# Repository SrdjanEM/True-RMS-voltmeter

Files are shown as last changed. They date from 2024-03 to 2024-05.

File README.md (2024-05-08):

# Voltage Measurement System with LED Display

## Overview
This project presents a comprehensive solution for measuring and displaying AC voltage levels accurately. Utilizing the ICL7107 analog-to-digital converter (ADC) with a precision of 3½ digits, the system offers high-precision voltage readings in a digital format, directly interfacing with LED displays for easy readability. Designed for minimal power consumption, it is particularly suited for battery-operated devices.

## Key Features
- **High Precision Measurement:** Leverages the ICL7107 ADC for accurate voltage reading.
- **Efficient Display:** Features four 7-segment SA08-11YWA LED displays for clear output visibility.
- **Energy Efficient:** Optimized for low power consumption, ideal for battery-operated implementations.
- **Flexible Connectivity:** Utilizes FFC (Flat Flexible Cable) connectors for seamless integration and ease of maintenance.
- **Robust PCB Design:** A dual-layer PCB design with a focus on electromagnetic stability and efficiency. Features copper pours for GND on the back layer to enhance device reliability.

## Hardware Components
- **ICL7107 ADC:** The core component for analog-to-digital conversion, offering direct connectivity to LED displays.
- **AD737:** Outputs RMS value of the measured AC voltage, interfaced with the ICL7107.
- **SA08-11YWA LED Displays:** Four 7-segment displays with common anode configuration, powered by 5V.
- **FFC Connectors:** Provides a flexible and secure connection between the LED displays and the main PCB.
- **PCB Materials:** Utilizes FR4 for the dielectric layer and ENIG (Electroless Nickel Immersion Gold) for the copper surface finish for enhanced durability and solderability.

## Full schematic 
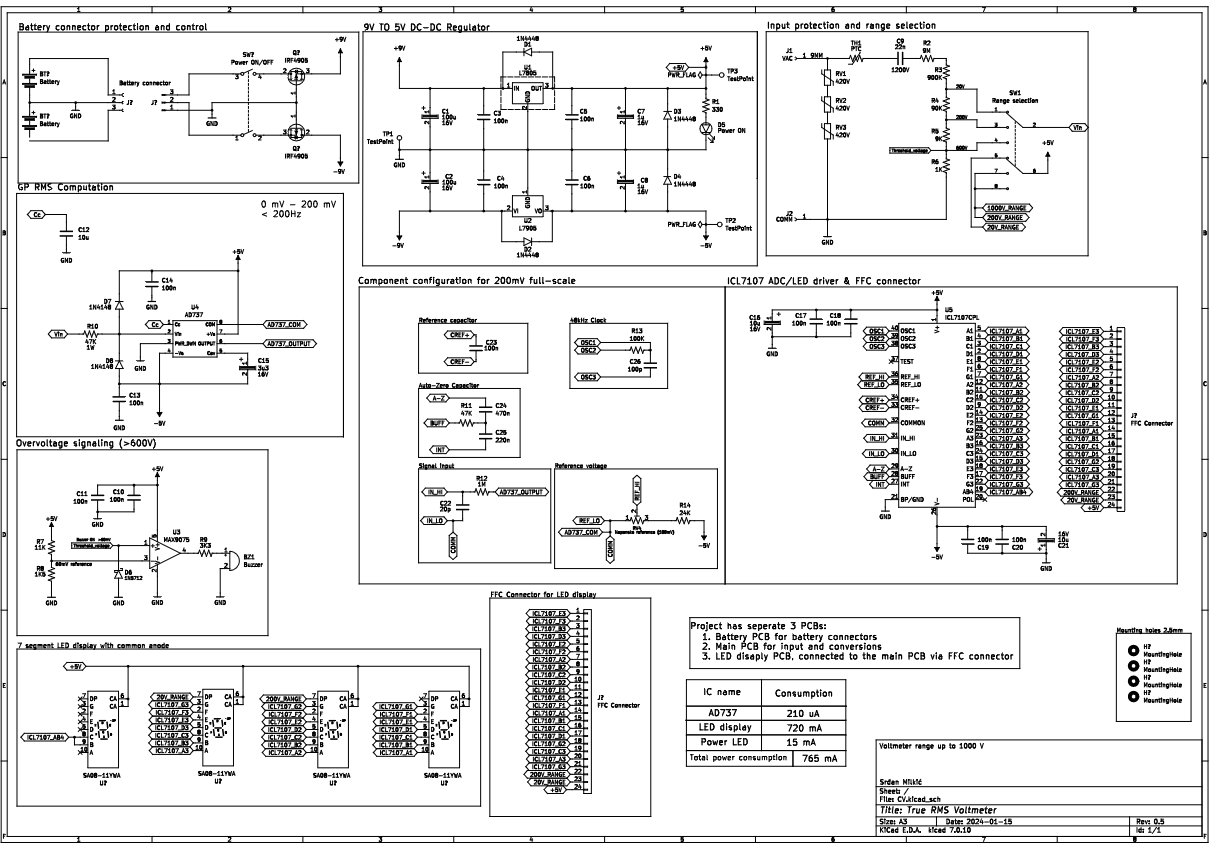
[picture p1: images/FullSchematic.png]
Schematic Better quality PDF in the repo

## PCB
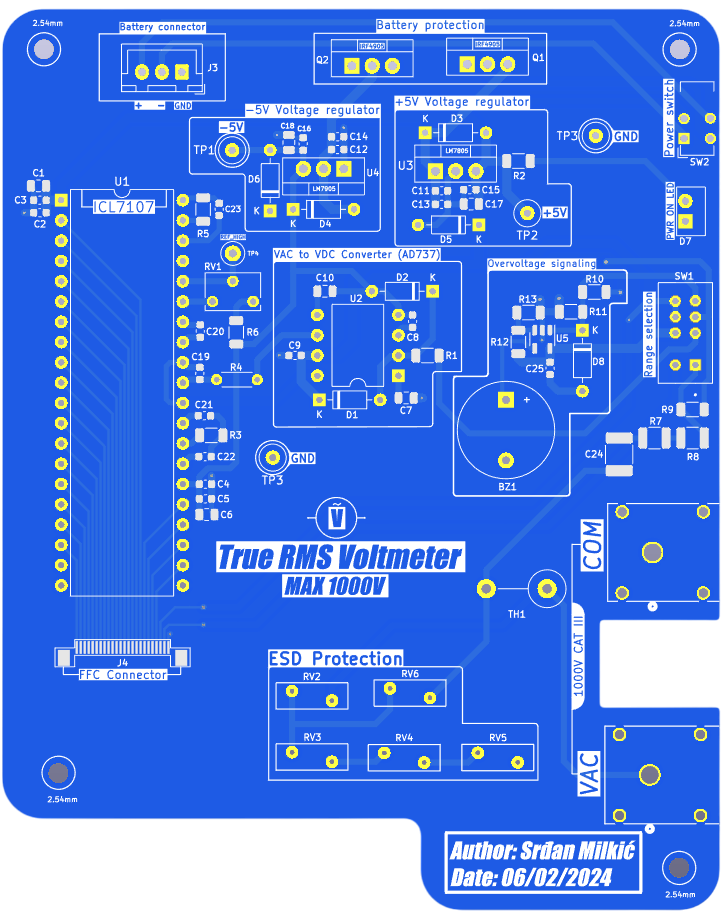
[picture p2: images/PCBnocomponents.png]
PCB PCB without components

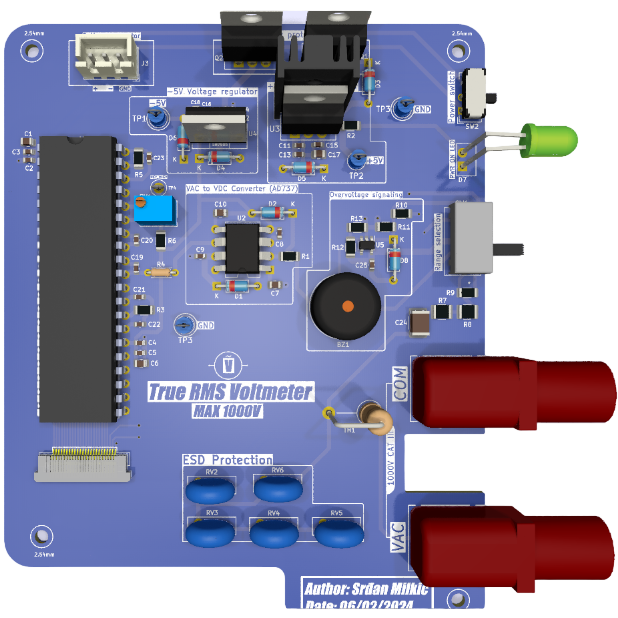
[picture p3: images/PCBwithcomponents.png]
PCB PCB with components


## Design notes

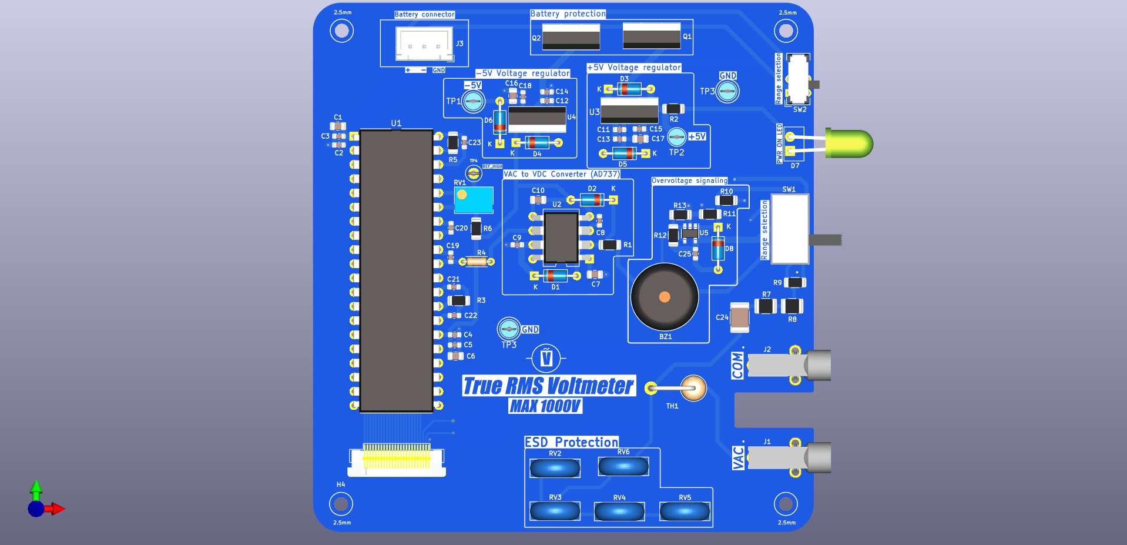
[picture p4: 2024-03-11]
True RMS Voltmeter [KiCad 7.0]/True RMS Voltmeter/Top.png

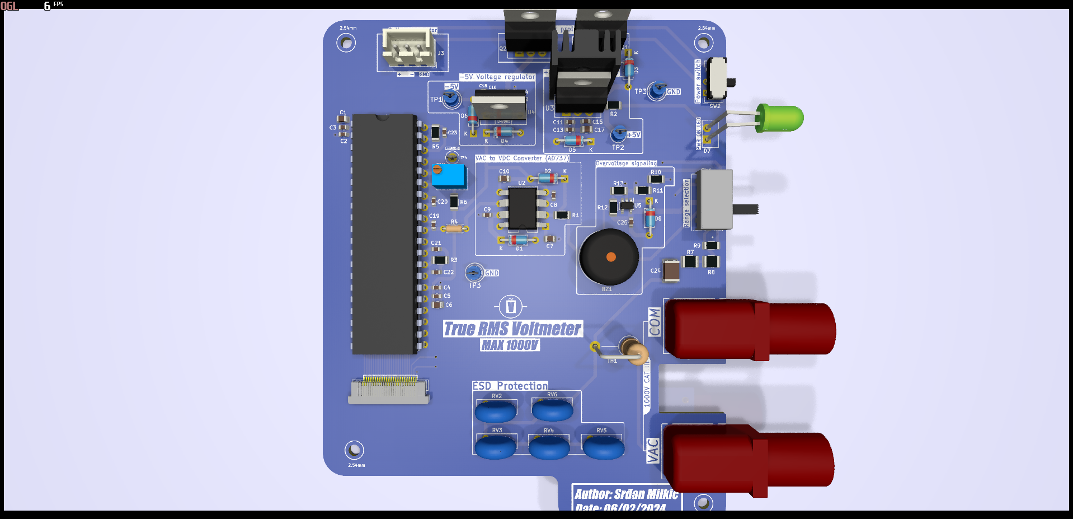
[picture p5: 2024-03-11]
True RMS Voltmeter [KiCad 7.0]/True RMS Voltmeter/TOP VIEW PCB 3D.png

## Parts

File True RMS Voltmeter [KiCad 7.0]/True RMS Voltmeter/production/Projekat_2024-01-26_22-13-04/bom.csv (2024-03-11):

Designator | Footprint | Quantity | Value | LCSC Part #
C1, C6 | 1210 | 2 | 10u
C10 | 1210 | 1 | 3u3
C11, C12 | 1210 | 2 | 100u
C13, C14, C15, C16, C2, C20, C3, C4, C5 | 1210 | 9 | 100n
C17, C18 | 1206 | 2 | 1u
C19 | 1210 | 1 | 20p
C21 | 1206 | 1 | 470n
C22 | 1206 | 1 | 220n
C23 | 1206 | 1 | 100p
C24 | C_Rect_L7.2mm_W11.0mm_P5.00mm_FKS2_FKP2_MKS2_MKP2 | 1 | 22n
C7 | 1206 | 1 | 10u
C8, C9 | 1206 | 2 | 100n
D1, D2 | D_DO-35_SOD27_P7.62mm_Horizontal | 2 | 1N4148
D3, D4, D5, D6 | D_DO-35_SOD27_P7.62mm_Horizontal | 4 | 1N4448
D7 | LED_D5.0mm_Horizontal_O6.35mm_Z15.0mm | 1 | Power ON
H1, H2, H3, H4 | MountingHole_2.5mm | 4 | MountingHole
J1 | TE_350180 | 1 | VAC
J2 | TE_350180 | 1 | COMM
J3 | JST_XH_B3B-XH-A_1x03_P2.50mm_Vertical | 1 | Conn_01x03_Male
J6 | FPC_24 | 1 | FPC Connector
Q1, Q2 | TO-220-3_Vertical | 2 | IRF4905
R1, R3 | 1206 | 2 | 47K
R10 | 1206 | 1 | 9K
R11 | 1206 | 1 | 1K
R12 | 1206 | 1 | 11K
R13 | 1206 | 1 | 1K5
R2 | 1206 | 1 | 330
R4 | 1812 | 1 | 1M
R5 | 1206 | 1 | 100K
R6 | 1206 | 1 | 24K
R9 | 1206 | 1 | 90K
RV1 | Potentiometer_Bourns_3266W_Vertical | 1 | Naponska referenca (100mV)
SW1 | SW_EG2310 | 1 | Range selection
SW2 | SW_CuK_JS202011AQN_DPDT_Angled | 1 | Power ON/OFF
TH1 | R_Axial_DIN0414_L11.9mm_D4.5mm_P7.62mm_Vertical | 1 | PTC
U1 | DIP-40_W15.24mm | 1 | ICL7107CPL
U2 | DIP-8_W10.16mm | 1 | AD737
U3 | TO-220-3_Vertical | 1 | L7805
U4 | TO-220-3_Vertical | 1 | L7905

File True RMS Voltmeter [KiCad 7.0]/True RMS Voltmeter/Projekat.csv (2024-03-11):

Source: | C:\Users\srdja\OneDrive\Radna površina\PRIUMS\Projekat\Projekat.kicad_sch
Date: | 1/13/2024 11:18:58 PM
Tool: | Eeschema (6.0.11)
Generator: | C:\Program Files\KiCad\6.0\bin\scripting\plugins/bom_csv_grouped_by_value.py
Component Count: | 52
Individual Components:
Item | Qty | Reference(s) | Value | LibPart | Footprint | Datasheet | Availability | Check_prices | Description | MANUFACTURER | MAXIMUM_PACKAGE_HEIGHT | MF | MP | PARTREV | Package | Price | Purchase-URL | SNAPEDA_PN | STANDARD | SnapEDA_Link
 |  | BZ1 | Buzzer | Device:Buzzer | Buzzer_Beeper:Buzzer_12x9.5RM7.6 | ~
 |  | C1 | 0.022uF | Device:C | Capacitor_THT:C_Rect_L26.5mm_W11.5mm_P22.50mm_MKS4 | ~
 |  | C2 | 1uF | PRIUMS_STANDARD:Cap_pol | Capacitor_SMD:C_1210_3225Metric
 |  | C3 | 100nF | Device:C | Capacitor_SMD:C_1210_3225Metric | ~
 |  | C4 | 100nF | Device:C | Capacitor_SMD:C_1210_3225Metric | ~
 |  | C5 | 3.3uF | :Cap_pol_1 | Capacitor_SMD:C_1210_3225Metric
 |  | C6 | 100uF | PRIUMS_STANDARD:Cap_pol | Capacitor_SMD:C_1210_3225Metric
 |  | C7 | 100nF | Device:C | Capacitor_SMD:C_1210_3225Metric | ~
 |  | C8 | 100nF | Device:C | Capacitor_SMD:C_1210_3225Metric | ~
 |  | C9 | 100uF | PRIUMS_STANDARD:Cap_pol | Capacitor_SMD:C_1210_3225Metric
 |  | C10 | 20pF | Device:C | Capacitor_SMD:C_1210_3225Metric | ~
 |  | C11 | 0.1uF | Device:C | Capacitor_SMD:C_1210_3225Metric | ~
 |  | C12 | 0.47uF | Device:C | Capacitor_SMD:C_1206_3216Metric | ~
 |  | C13 | 0.22uF | Device:C | Capacitor_SMD:C_1206_3216Metric | ~
 |  | C14 | 100pF | Device:C | Capacitor_SMD:C_1206_3216Metric | ~
 |  | C15 | 100uF | PRIUMS_STANDARD:Cap_pol | Capacitor_SMD:C_1206_3216Metric
 |  | C16 | 100uF | PRIUMS_STANDARD:Cap_pol | Capacitor_SMD:C_1206_3216Metric
 |  | C17 | 10pF | Device:C | Capacitor_SMD:C_1206_3216Metric | ~
 |  | D1 | 1N4148 | :1N4148_1 | Diode_THT:D_DO-35_SOD27_P7.62mm_Horizontal | https://assets.nexperia.com/documents/data-sheet/1N4148_1N4448.pdf
 |  | D2 | 1N4148 | Diode:1N4148 | Diode_THT:D_DO-35_SOD27_P7.62mm_Horizontal | https://assets.nexperia.com/documents/data-sheet/1N4148_1N4448.pdf
 |  | D3 | 1N4448 | Diode:1N4448 | Diode_THT:D_DO-35_SOD27_P7.62mm_Horizontal | https://assets.nexperia.com/documents/data-sheet/1N4148_1N4448.pdf
 |  | D4 | Green | Device:LED | LED_THT:LED_D5.0mm_Horizontal_O6.35mm_Z15.0mm | ~
 |  | D5 | 1N4002 | Diode:1N4002 | Diode_THT:D_DO-41_SOD81_P10.16mm_Horizontal | http://www.vishay.com/docs/88503/1n4001.pdf
 |  | IC1 | AD737 | PRIUMS_STANDARD:AD737 | Package_DIP:DIP-8_W10.16mm | https://www.analog.com/media/en/technical-documentation/data-sheets/ad737.pdf
 |  | J1 | COMM | Connector:Conn_01x01_Female | Connector:Banana_Jack_1Pin | ~
 |  | J2 | V | Connector:Conn_01x01_Female | Connector:Banana_Jack_1Pin | ~
 |  | J3 | Battery Connector | Connector_Generic:Conn_01x02 |  | ~
 |  | R1 | 1M | Device:R_US | Resistor_SMD:R_1812_4532Metric | ~
 |  | R2 | 11K | Device:R_US | Resistor_SMD:R_1206_3216Metric | ~
 |  | R3 | 1.5K | Device:R_US | Resistor_SMD:R_1206_3216Metric | ~
 |  | R4 | 11M | Device:R_US | Resistor_SMD:R_1210_3225Metric | ~
 |  | R5 | 47K | Device:R_US | Resistor_SMD:R_1206_3216Metric | ~
 |  | R6 | 330 | Device:R_US | Resistor_SMD:R_1206_3216Metric | ~
 |  | R7 | 47K | Device:R_US | Resistor_SMD:R_1206_3216Metric | ~
 |  | R8 | 100K | Device:R_US | Resistor_SMD:R_1206_3216Metric | ~
 |  | R9 | 100K | Device:R_US | Resistor_SMD:R_1206_3216Metric | ~
 |  | R10 | 24K | Device:R_US | Resistor_SMD:R_1206_3216Metric | ~
 |  | R11 | 10K | Device:R_US | Resistor_SMD:R_1206_3216Metric | ~
 |  | R12 | 1.1K | Device:R_US | Resistor_SMD:R_1206_3216Metric | ~
 |  | RV1 | 1K | Device:R_Potentiometer_Trim_US | Potentiometer_THT:Potentiometer_Bourns_3266W_Vertical | ~
 |  | RV2 | 430V | Device:Varistor | Varistor:RV_Disc_D12mm_W3.9mm_P7.5mm | ~
 |  | RV3 | 430V | Device:Varistor | Varistor:RV_Disc_D12mm_W3.9mm_P7.5mm | ~
 |  | RV4 | 430V | Device:Varistor | Varistor:RV_Disc_D12mm_W3.9mm_P7.5mm | ~
 |  | RV5 | 430V | Device:Varistor | Varistor:RV_Disc_D12mm_W3.9mm_P7.5mm | ~
 |  | RV6 | 430V | Device:Varistor | Varistor:RV_Disc_D12mm_W3.9mm_P7.5mm | ~
 |  | S1 | EG2310 | PRIUMS_STANDARD:EG2310 | EG2310:SW_EG2310 |  | In Stock | https://www.snapeda.com/parts/EG2310/E-Switch/view-part/?ref=eda | Slide Switch DP3T Through Hole, Right Angle | E-Switch | 4.7mm | E-Switch | EG2310 | - | None | None | https://www.snapeda.com/api/url_track_click_mouser/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 | EG2310 | Manufacturer Recommendations | https://www.snapeda.com/parts/EG2310/E-Switch/view-part/?ref=snap
 |  | TH1 | PTC | PRIUMS_STANDARD:PTC | Resistor_THT:R_Axial_DIN0414_L11.9mm_D4.5mm_P7.62mm_Vertical | https://www.vishay.com/docs/29072/ptccl.pdf
 |  | U1 | ICL7107CPL | Analog_ADC:ICL7107CPL | Package_DIP:DIP-40_W15.24mm | https://www.renesas.com/eu/en/www/doc/datasheet/icl7106-07-07s.pdf
 |  | U2 | DE113-XX-XX | Display_Character:DE113-XX-XX | Display_7Segment:DE113-XX-XX | http://www.display-elektronik.de/filter/DE113-MS-20_75.pdf
 |  | U3 | L7806 | Regulator_Linear:L7806 | Package_TO_SOT_THT:TO-220-3_Horizontal_TabDown | http://www.st.com/content/ccc/resource/technical/document/datasheet/41/4f/b3/b0/12/d4/47/88/CD00000444.pdf/files/CD00000444.pdf/jcr:content/translations/en.CD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
 |  | U4 | L7905 | Regulator_Linear:L7905 | Package_TO_SOT_THT:TO-220-3_Horizontal_TabDown | http://www.st.com/content/ccc/resource/technical/document/datasheet/c9/16/86/41/c7/2b/45/f2/CD00000450.pdf/files/CD00000450.pdf/jcr:content/translations/en.CD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
 |  | U5 | AD8561 | Comparator:AD8561 | Package_DIP:DIP-8_W7.62mm | https://www.analog.com/media/en/technical-documentation/data-sheets/ad8561.pdf
Collated Components:
Item | Qty | Reference(s) | Value | LibPart | Footprint | Datasheet | Availability | Check_prices | Description | MANUFACTURER | MAXIMUM_PACKAGE_HEIGHT | MF | MP | PARTREV | Package | Price | Purchase-URL | SNAPEDA_PN | STANDARD | SnapEDA_Link
1 | 1 | BZ1 | Buzzer | Device:Buzzer | Buzzer_Beeper:Buzzer_12x9.5RM7.6 | ~
2 | 1 | C1 | 0.022uF | Device:C | Capacitor_THT:C_Rect_L26.5mm_W11.5mm_P22.50mm_MKS4 | ~
3 | 1 | C2 | 1uF | PRIUMS_STANDARD:Cap_pol | Capacitor_SMD:C_1210_3225Metric
4 | 4 | C3, C4, C7, C8 | 100nF | Device:C | Capacitor_SMD:C_1210_3225Metric | ~
5 | 1 | C5 | 3.3uF | :Cap_pol_1 | Capacitor_SMD:C_1210_3225Metric
6 | 2 | C6, C9 | 100uF | PRIUMS_STANDARD:Cap_pol | Capacitor_SMD:C_1210_3225Metric
7 | 1 | C10 | 20pF | Device:C | Capacitor_SMD:C_1210_3225Metric | ~
8 | 1 | C11 | 0.1uF | Device:C | Capacitor_SMD:C_1210_3225Metric | ~
9 | 1 | C12 | 0.47uF | Device:C | Capacitor_SMD:C_1206_3216Metric | ~
10 | 1 | C13 | 0.22uF | Device:C | Capacitor_SMD:C_1206_3216Metric | ~
11 | 1 | C14 | 100pF | Device:C | Capacitor_SMD:C_1206_3216Metric | ~
12 | 2 | C15, C16 | 100uF | PRIUMS_STANDARD:Cap_pol | Capacitor_SMD:C_1206_3216Metric
13 | 1 | C17 | 10pF | Device:C | Capacitor_SMD:C_1206_3216Metric | ~
14 | 1 | D1 | 1N4148 | :1N4148_1 | Diode_THT:D_DO-35_SOD27_P7.62mm_Horizontal | https://assets.nexperia.com/documents/data-sheet/1N4148_1N4448.pdf
15 | 1 | D2 | 1N4148 | Diode:1N4148 | Diode_THT:D_DO-35_SOD27_P7.62mm_Horizontal | https://assets.nexperia.com/documents/data-sheet/1N4148_1N4448.pdf
16 | 1 | D3 | 1N4448 | Diode:1N4448 | Diode_THT:D_DO-35_SOD27_P7.62mm_Horizontal | https://assets.nexperia.com/documents/data-sheet/1N4148_1N4448.pdf
17 | 1 | D4 | Green | Device:LED | LED_THT:LED_D5.0mm_Horizontal_O6.35mm_Z15.0mm | ~
18 | 1 | D5 | 1N4002 | Diode:1N4002 | Diode_THT:D_DO-41_SOD81_P10.16mm_Horizontal | http://www.vishay.com/docs/88503/1n4001.pdf
19 | 1 | IC1 | AD737 | PRIUMS_STANDARD:AD737 | Package_DIP:DIP-8_W10.16mm | https://www.analog.com/media/en/technical-documentation/data-sheets/ad737.pdf
20 | 1 | J1 | COMM | Connector:Conn_01x01_Female | Connector:Banana_Jack_1Pin | ~
21 | 1 | J2 | V | Connector:Conn_01x01_Female | Connector:Banana_Jack_1Pin | ~
22 | 1 | J3 | Battery Connector | Connector_Generic:Conn_01x02 |  | ~
23 | 1 | R1 | 1M | Device:R_US | Resistor_SMD:R_1812_4532Metric | ~
24 | 1 | R2 | 11K | Device:R_US | Resistor_SMD:R_1206_3216Metric | ~
25 | 1 | R3 | 1.5K | Device:R_US | Resistor_SMD:R_1206_3216Metric | ~
26 | 1 | R4 | 11M | Device:R_US | Resistor_SMD:R_1210_3225Metric | ~
27 | 2 | R5, R7 | 47K | Device:R_US | Resistor_SMD:R_1206_3216Metric | ~
28 | 1 | R6 | 330 | Device:R_US | Resistor_SMD:R_1206_3216Metric | ~
29 | 2 | R8, R9 | 100K | Device:R_US | Resistor_SMD:R_1206_3216Metric | ~
30 | 1 | R10 | 24K | Device:R_US | Resistor_SMD:R_1206_3216Metric | ~
31 | 1 | R11 | 10K | Device:R_US | Resistor_SMD:R_1206_3216Metric | ~
32 | 1 | R12 | 1.1K | Device:R_US | Resistor_SMD:R_1206_3216Metric | ~
33 | 1 | RV1 | 1K | Device:R_Potentiometer_Trim_US | Potentiometer_THT:Potentiometer_Bourns_3266W_Vertical | ~
34 | 5 | RV2, RV3, RV4, RV5, RV6 | 430V | Device:Varistor | Varistor:RV_Disc_D12mm_W3.9mm_P7.5mm | ~
35 | 1 | S1 | EG2310 | PRIUMS_STANDARD:EG2310 | EG2310:SW_EG2310 |  | In Stock | https://www.snapeda.com/parts/EG2310/E-Switch/view-part/?ref=eda | Slide Switch DP3T Through Hole, Right Angle | E-Switch | 4.7mm | E-Switch | EG2310 | - | None | None | https://www.snapeda.com/api/url_track_click_mouser/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 | EG2310 | Manufacturer Recommendations | https://www.snapeda.com/parts/EG2310/E-Switch/view-part/?ref=snap
36 | 1 | TH1 | PTC | PRIUMS_STANDARD:PTC | Resistor_THT:R_Axial_DIN0414_L11.9mm_D4.5mm_P7.62mm_Vertical | https://www.vishay.com/docs/29072/ptccl.pdf
37 | 1 | U1 | ICL7107CPL | Analog_ADC:ICL7107CPL | Package_DIP:DIP-40_W15.24mm | https://www.renesas.com/eu/en/www/doc/datasheet/icl7106-07-07s.pdf
38 | 1 | U2 | DE113-XX-XX | Display_Character:DE113-XX-XX | Display_7Segment:DE113-XX-XX | http://www.display-elektronik.de/filter/DE113-MS-20_75.pdf
39 | 1 | U3 | L7806 | Regulator_Linear:L7806 | Package_TO_SOT_THT:TO-220-3_Horizontal_TabDown | http://www.st.com/content/ccc/resource/technical/document/datasheet/41/4f/b3/b0/12/d4/47/88/CD00000444.pdf/files/CD00000444.pdf/jcr:content/translations/en.CD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
40 | 1 | U4 | L7905 | Regulator_Linear:L7905 | Package_TO_SOT_THT:TO-220-3_Horizontal_TabDown | http://www.st.com/content/ccc/resource/technical/document/datasheet/c9/16/86/41/c7/2b/45/f2/CD00000450.pdf/files/CD00000450.pdf/jcr:content/translations/en.CD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
41 | 1 | U5 | AD8561 | Comparator:AD8561 | Package_DIP:DIP-8_W7.62mm | https://www.analog.com/media/en/technical-documentation/data-sheets/ad8561.pdf

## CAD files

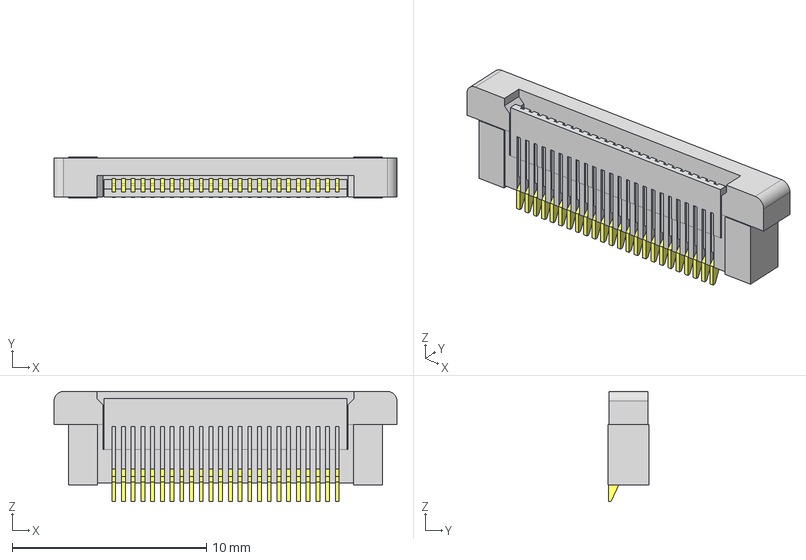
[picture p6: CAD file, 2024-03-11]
True RMS Voltmeter [KiCad 7.0]/EG2310/3D/ZF5S-24-01-T-WT.stp
17.6 x 2.10 x 5.67 mm
C-297-24-01_pins
ZF5S-24-01-WT_socket

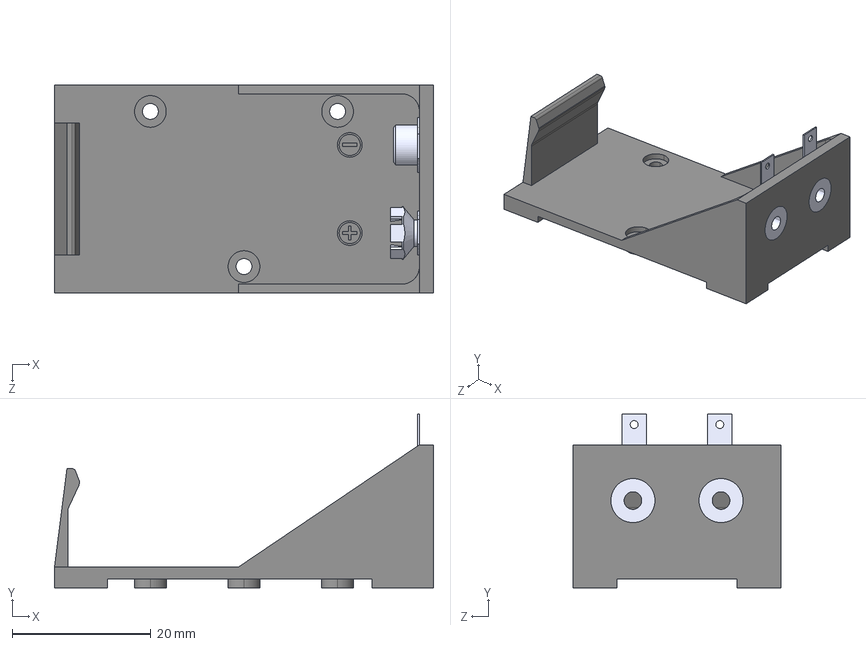
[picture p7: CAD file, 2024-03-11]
True RMS Voltmeter [KiCad 7.0]/Footprint/BH9VL--3DModel-STEP-56544/BH9VL--3DModel-STEP-56544.STEP
54.6 x 25.1 x 30.0 mm

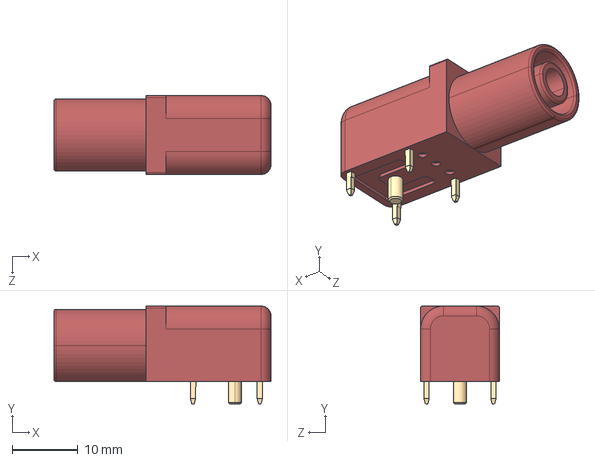
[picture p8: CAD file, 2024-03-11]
True RMS Voltmeter [KiCad 7.0]/Footprint/FCR7350R/FCR7350R--3DModel-STEP-56544.STEP
33.0 x 14.9 x 12.0 mm

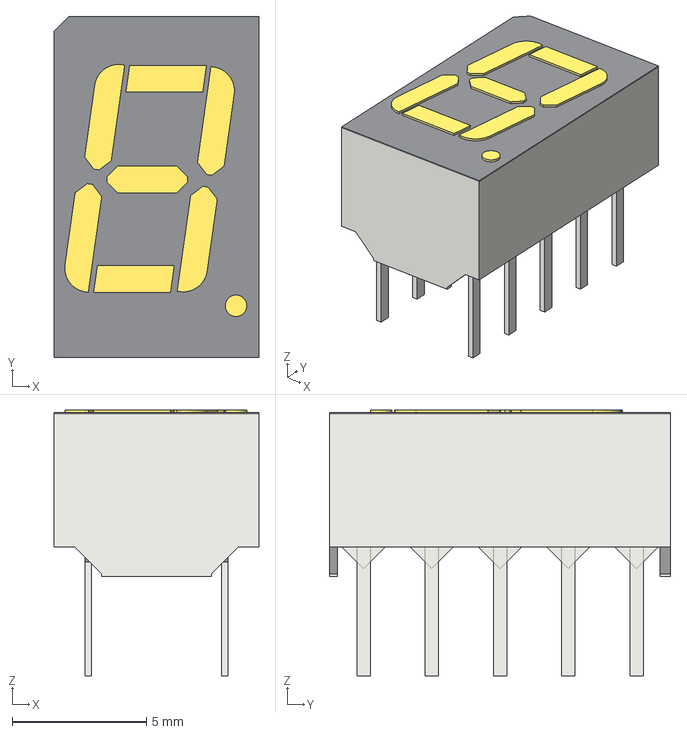
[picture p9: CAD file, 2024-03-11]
True RMS Voltmeter [KiCad 7.0]/Footprint/HDSP-7401.step
7.62 x 12.7 x 9.90 mm

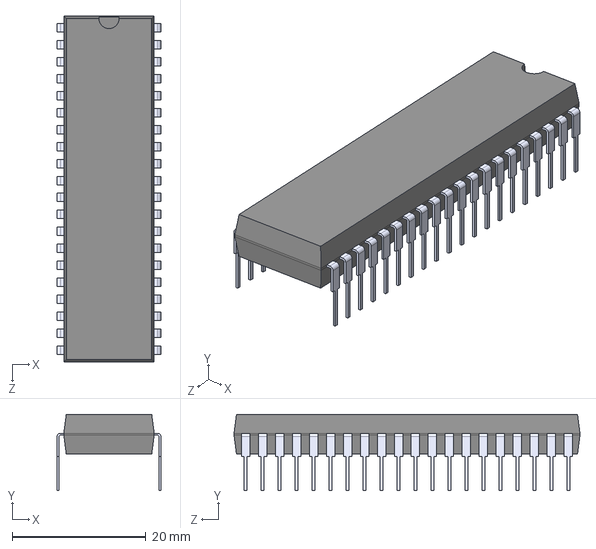
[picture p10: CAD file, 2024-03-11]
True RMS Voltmeter [KiCad 7.0]/Footprint/ICL7107/ICL7107CPL--3DModel-STEP-1.STEP
15.5 x 11.4 x 51.8 mm

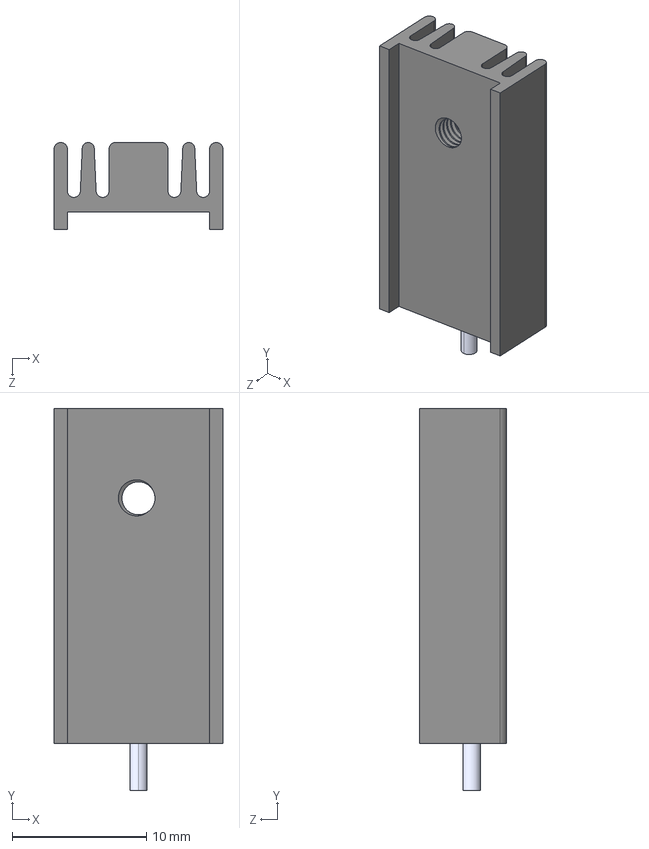
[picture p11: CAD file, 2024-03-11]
True RMS Voltmeter [KiCad 7.0]/Footprint/SK 95 25 STS TO 220/SK 95 25 STS TO 220--3DModel-STEP-269445.STEP
12.6 x 28.5 x 6.50 mm

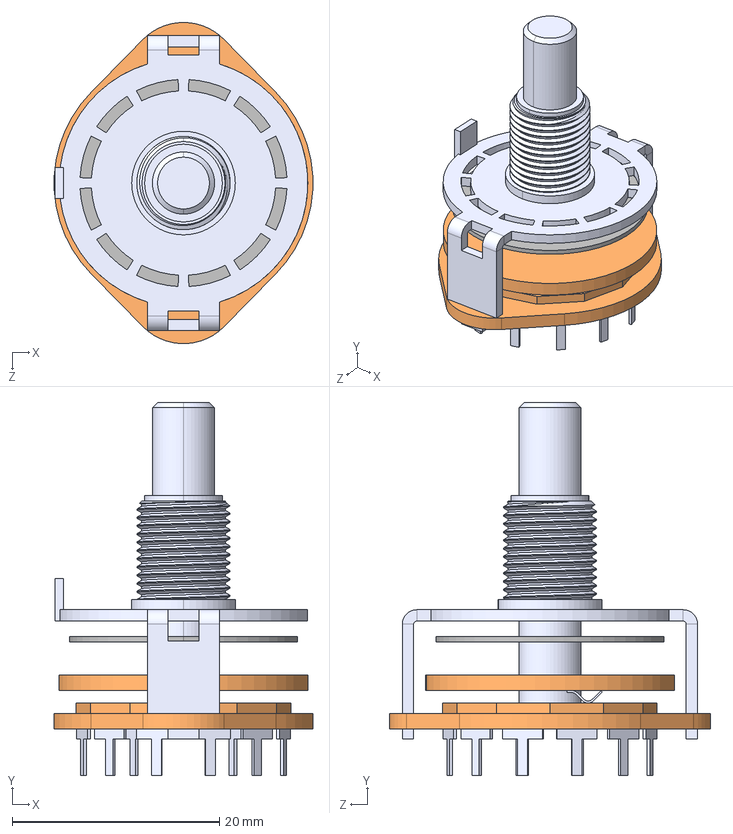
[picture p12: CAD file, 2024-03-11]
True RMS Voltmeter [KiCad 7.0]/Footprint/SR2512F-0206-19R0B-E9-N-W-159/SR2512F-0206-19R0B-E9-N-W-159--3DModel-STEP-56544.STEP
25.0 x 36.0 x 31.0 mm

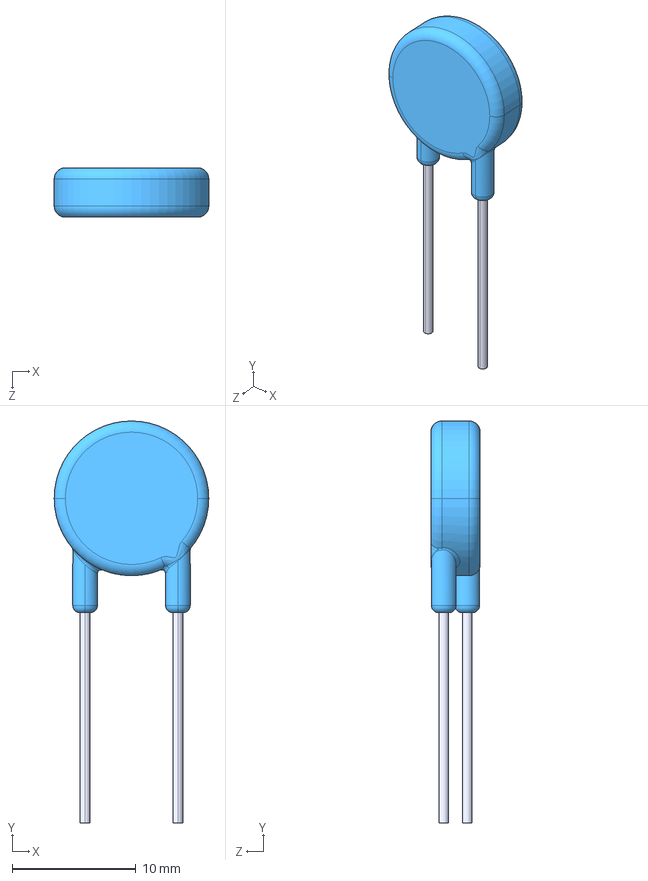
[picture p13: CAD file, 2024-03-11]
True RMS Voltmeter [KiCad 7.0]/MOV-10D561K.STEP
12.5 x 32.5 x 4.00 mm

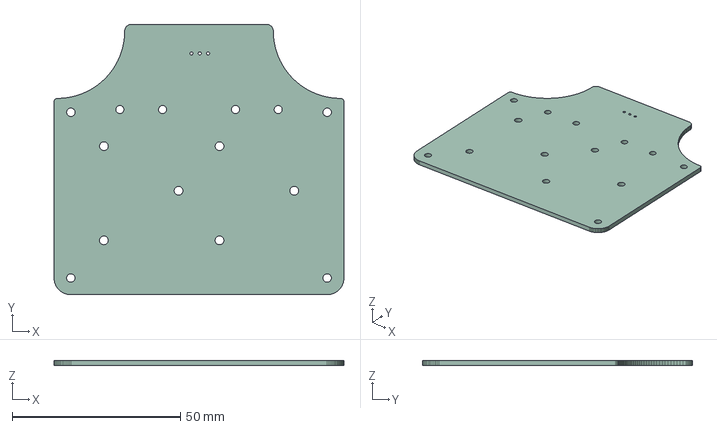
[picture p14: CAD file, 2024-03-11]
True RMS Voltmeter [KiCad 7.0]/True RMS Voltmeter/LCD Ploča/Baterija/Baterija.step
86.2 x 80.4 x 1.60 mm

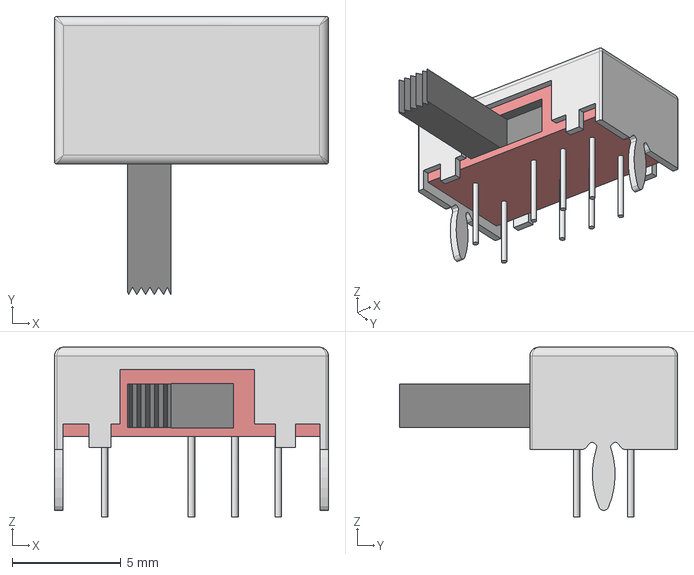
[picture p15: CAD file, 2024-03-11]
True RMS Voltmeter [KiCad 7.0]/EG2310/3D/EG2310.stp
12.6 x 12.8 x 7.80 mm

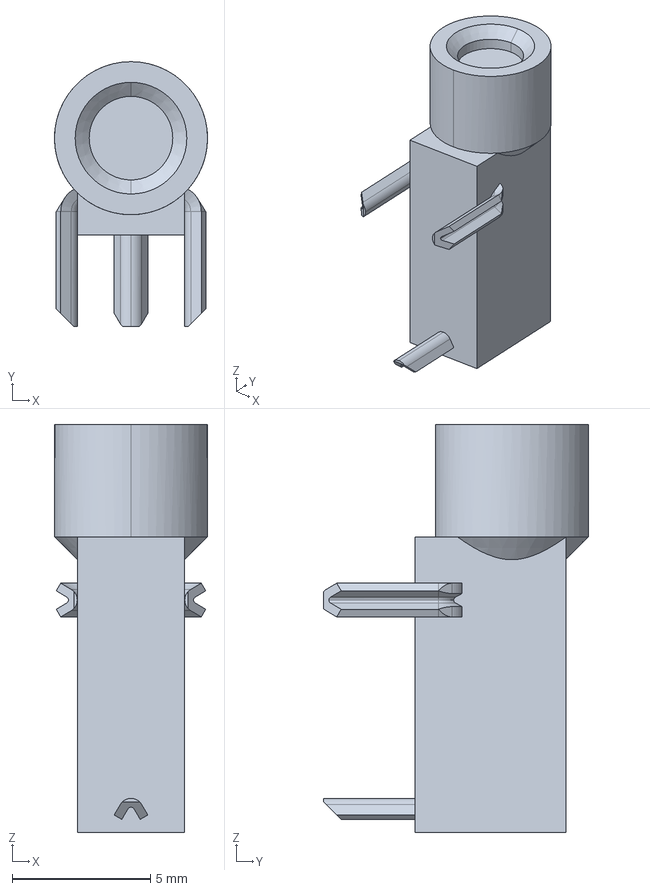
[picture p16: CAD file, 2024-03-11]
True RMS Voltmeter [KiCad 7.0]/Footprint/350180-9/350180-9.step
5.54 x 9.58 x 14.8 mm

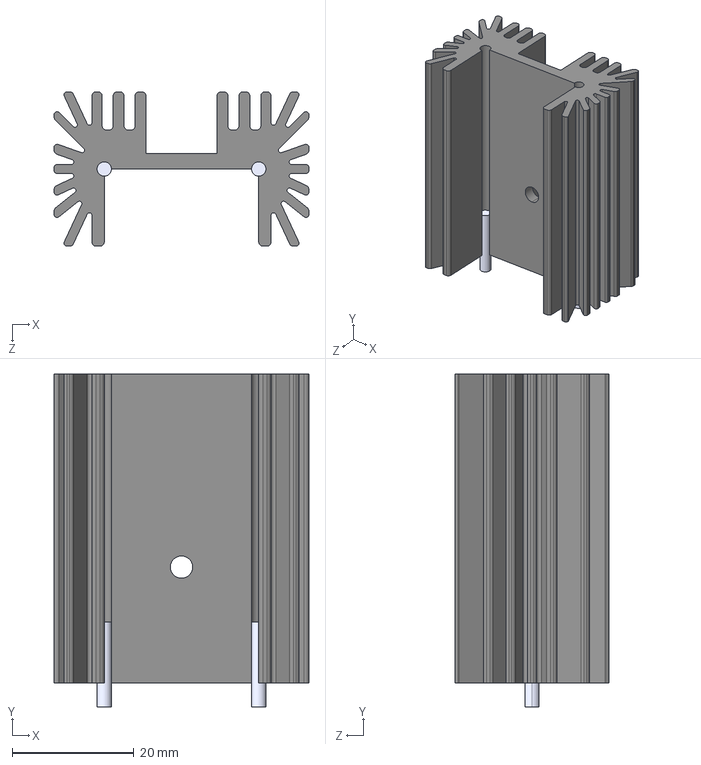
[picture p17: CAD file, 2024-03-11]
True RMS Voltmeter [KiCad 7.0]/Footprint/532702B02500G/532702B02500G.step
41.9 x 54.8 x 25.4 mm

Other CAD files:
True RMS Voltmeter [KiCad 7.0]/Footprint/ZF5S-24-01-T-WT/ZF5S-24-01-T-WT.stp

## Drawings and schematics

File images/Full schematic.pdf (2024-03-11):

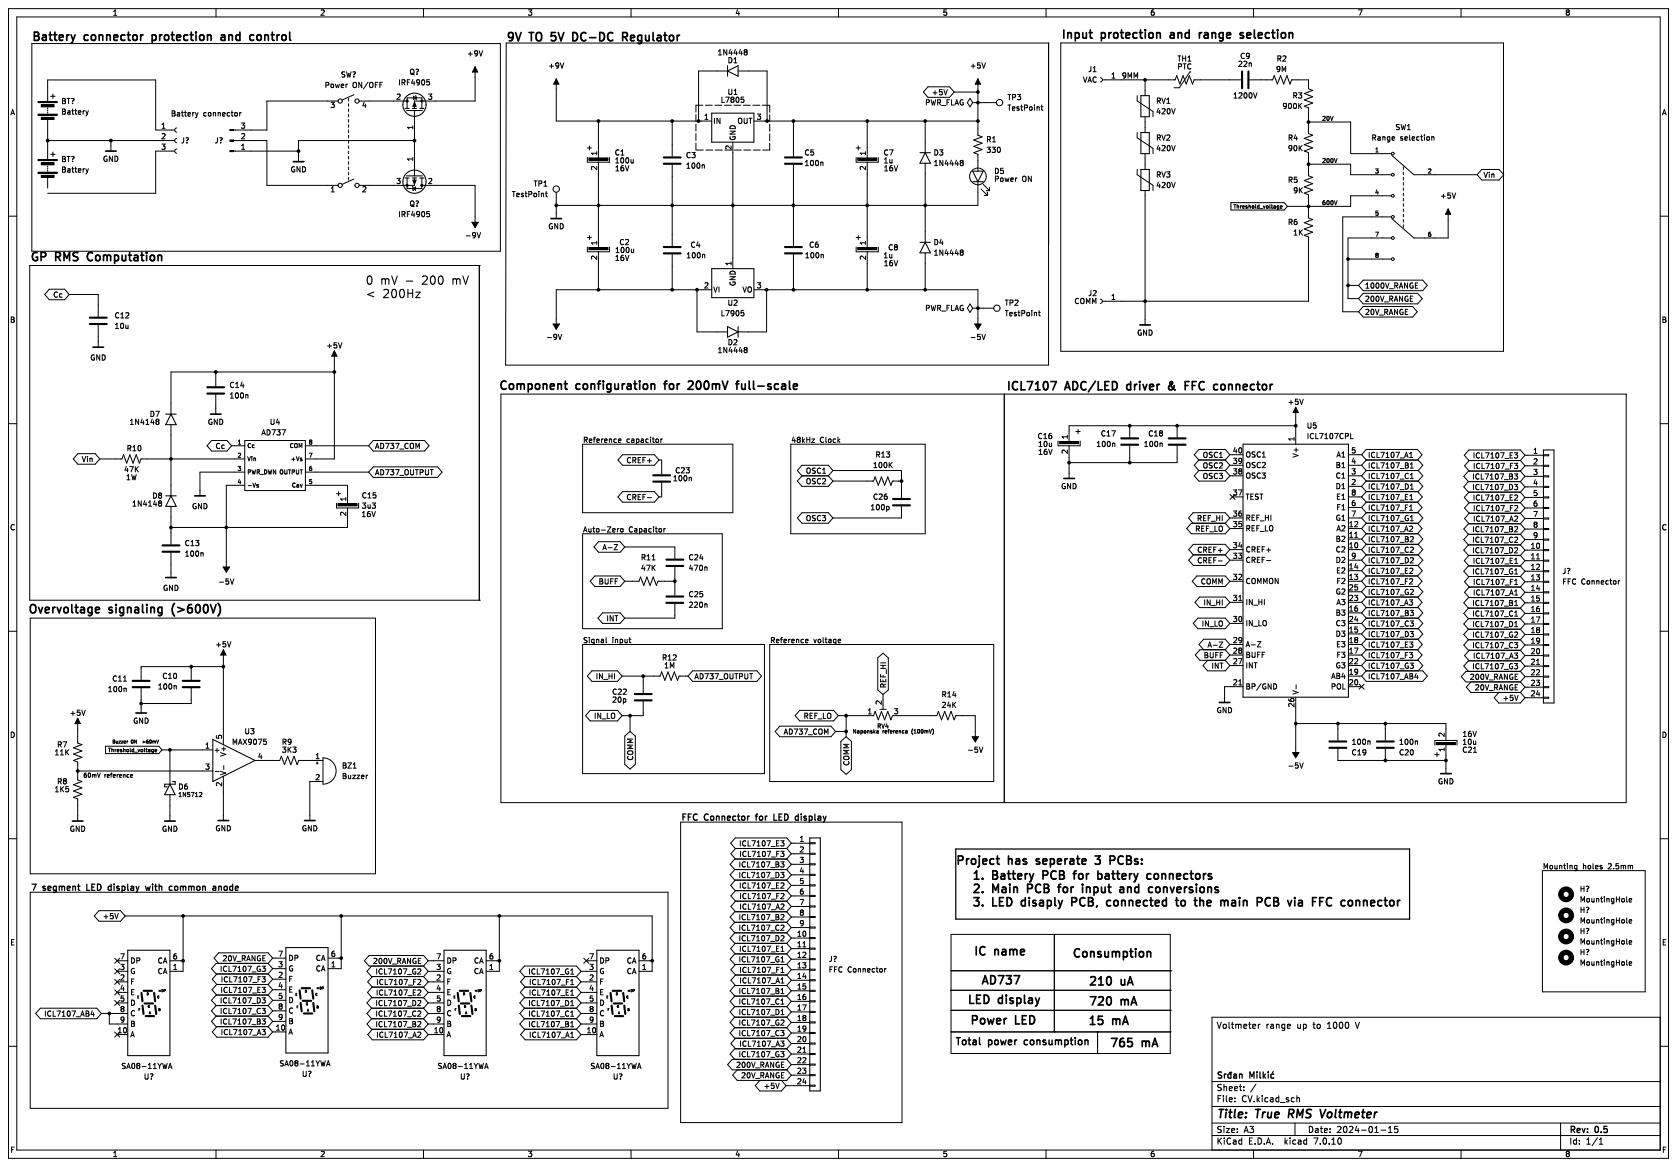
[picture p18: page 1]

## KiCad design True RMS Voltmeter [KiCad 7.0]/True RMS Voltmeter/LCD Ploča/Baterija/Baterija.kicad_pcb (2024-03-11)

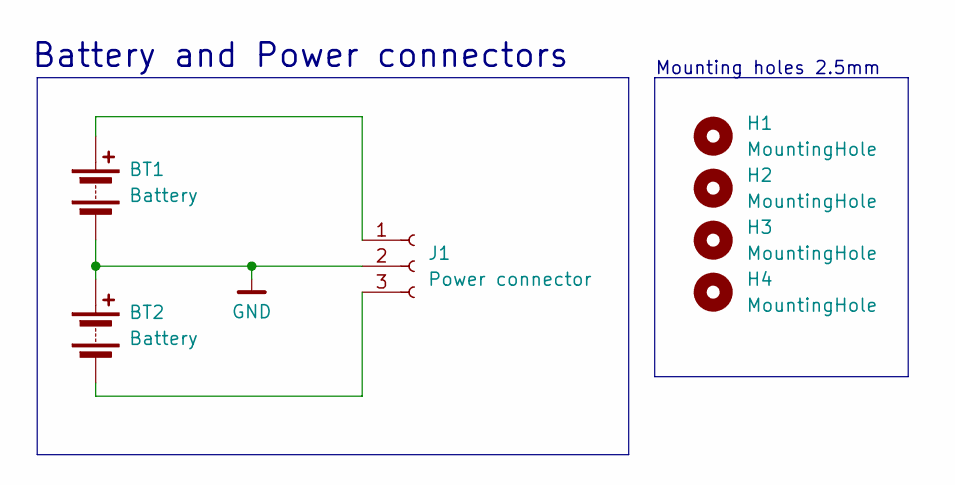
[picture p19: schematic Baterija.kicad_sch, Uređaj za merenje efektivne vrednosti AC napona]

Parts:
BT1, BT2: Battery; BatteryHolder_Eagle_12BH611-GR
H1, H2, H3, H4: MountingHole; MountingHole_2.5mm
J1: Power connector; JST_XH_B3B-XH-A_1x03_P2.50mm_Vertical

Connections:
GND: BT1.2 (-), BT2.1 (+), J1.2
unnamed: BT1.1 (+), J1.1
unnamed: BT2.2 (-), J1.3

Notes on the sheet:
Battery and Power connectors
Mounting holes 2.5mm

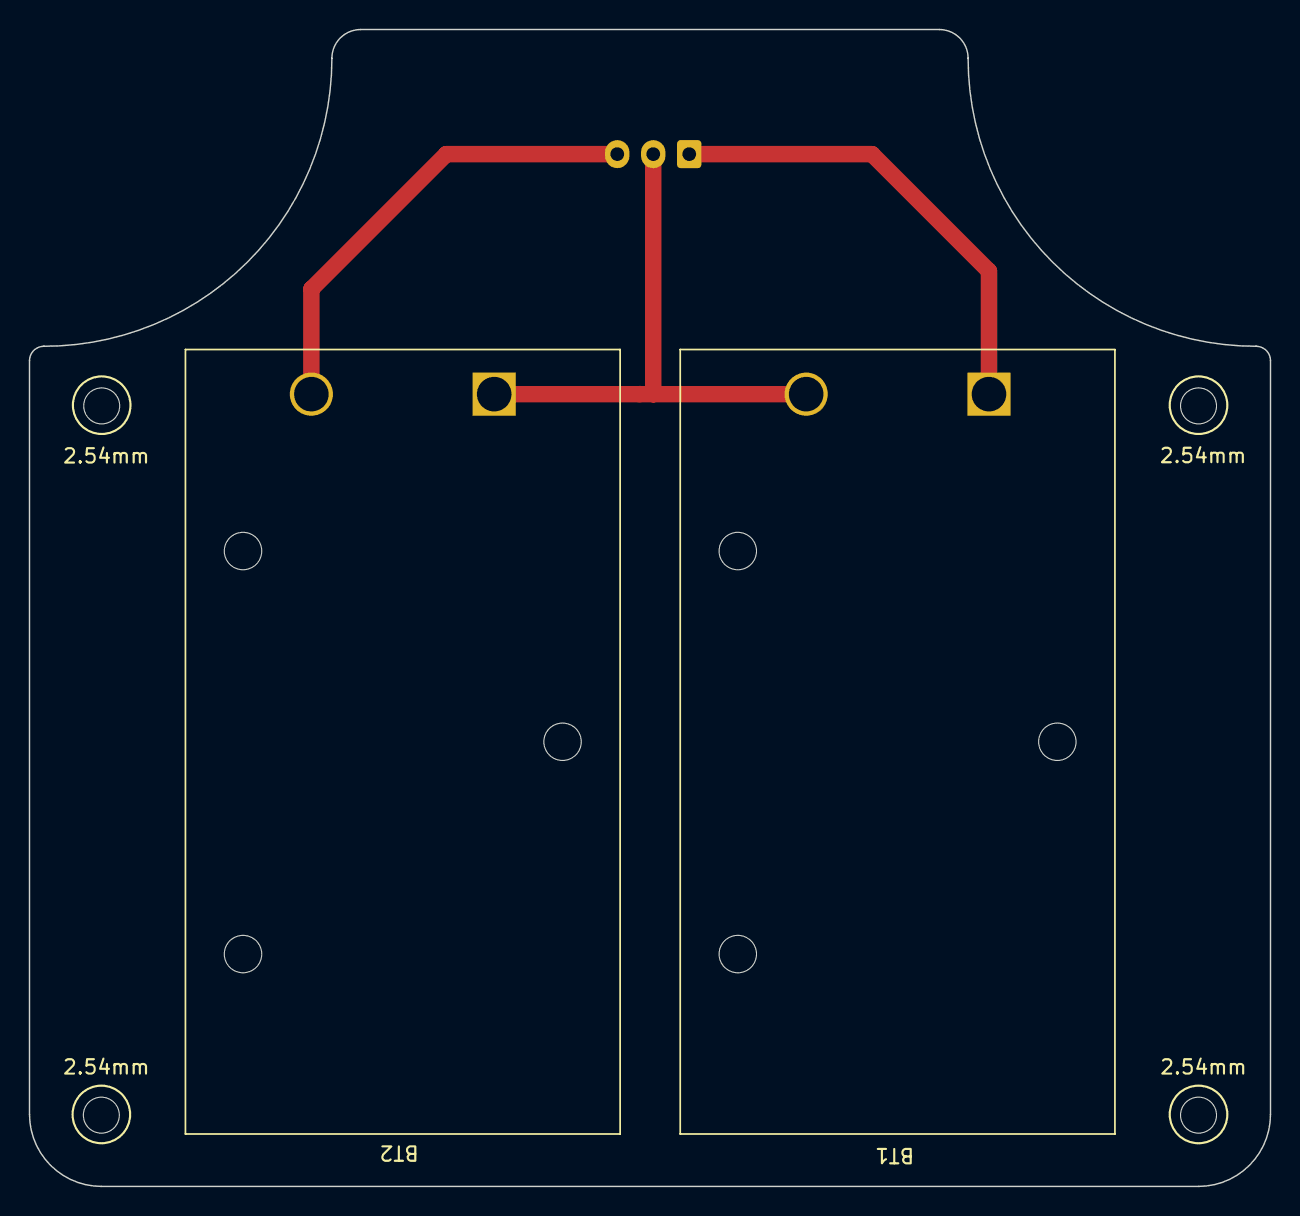
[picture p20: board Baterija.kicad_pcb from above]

Board: 2 copper layers, 86.2 x 80.4 mm, 7 parts (1 on the bottom side), 3 nets.

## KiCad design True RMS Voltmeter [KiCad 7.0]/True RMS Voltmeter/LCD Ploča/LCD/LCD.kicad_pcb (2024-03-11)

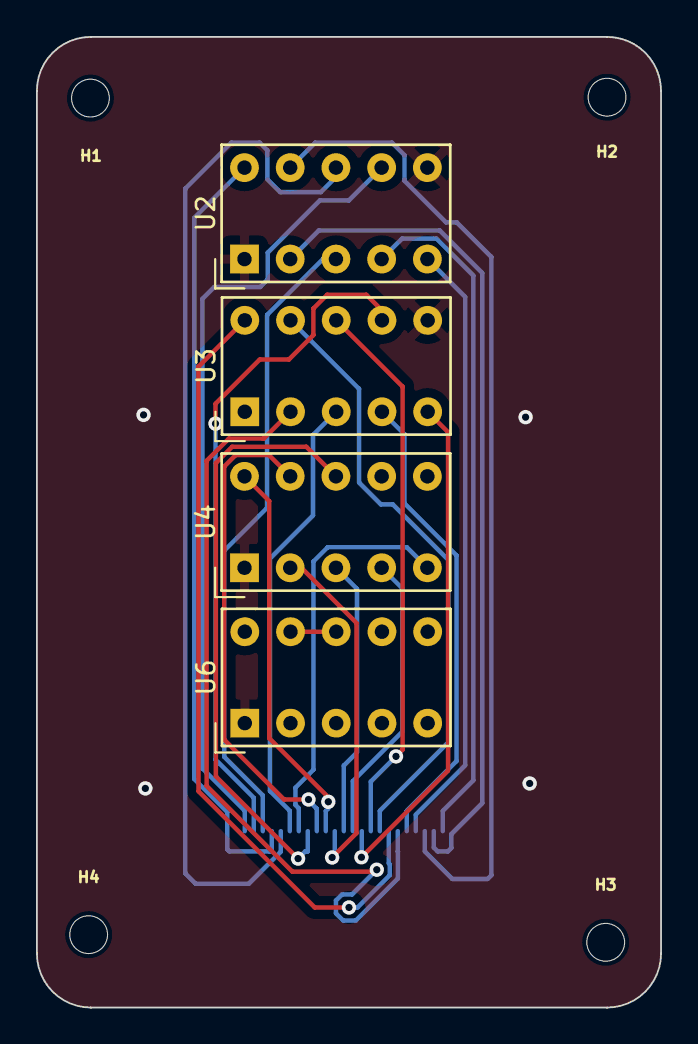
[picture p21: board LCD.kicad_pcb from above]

Board: 2 copper layers, 34.7 x 53.9 mm, 9 parts (1 on the bottom side), 25 nets.

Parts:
H1, H2, H3, H4: MountingHole; MountingHole_2.1mm
J1: FFC Connector; FPC_24
U2, U3, U4, U6: HDSP-7401

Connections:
20V_RANGE: J1.23, U2.7 (DP)
200V_RANGE: J1.22, U3.7 (DP)
+5V: J1.24, U2.1 (CA), U2.6 (CA), U3.1 (CA), U3.6 (CA), U4.1 (CA), U4.6 (CA), U6.1 (CA), U6.6 (CA)
ICL7107_A1: J1.14, U4.10 (A)
ICL7107_A2: J1.7, U3.10 (A)
ICL7107_A3: J1.20, U2.10 (A)
ICL7107_AB4: U6.8 (C), U6.9 (B)
ICL7107_B1: J1.15, U4.9 (B)
ICL7107_B2: J1.8, U3.9 (B)
ICL7107_B3: J1.3, U2.9 (B)
ICL7107_C1: J1.16, U4.8 (C)
ICL7107_C2: J1.9, U3.8 (C)
ICL7107_C3: J1.19, U2.8 (C)
ICL7107_D1: J1.17, U4.5 (D)
ICL7107_D2: J1.10, U3.5 (D)
ICL7107_D3: J1.4, U2.5 (D)
ICL7107_E1: J1.11, U4.4 (E)
ICL7107_E2: J1.5, U3.4 (E)
ICL7107_E3: J1.1, U2.4 (E)
ICL7107_F1: J1.13, U4.2 (F)
ICL7107_F2: J1.6, U3.2 (F)
ICL7107_F3: J1.2, U2.2 (F)
ICL7107_G1: J1.12, U4.3 (G)
ICL7107_G2: J1.18, U3.3 (G)
ICL7107_G3: J1.21, U2.3 (G)

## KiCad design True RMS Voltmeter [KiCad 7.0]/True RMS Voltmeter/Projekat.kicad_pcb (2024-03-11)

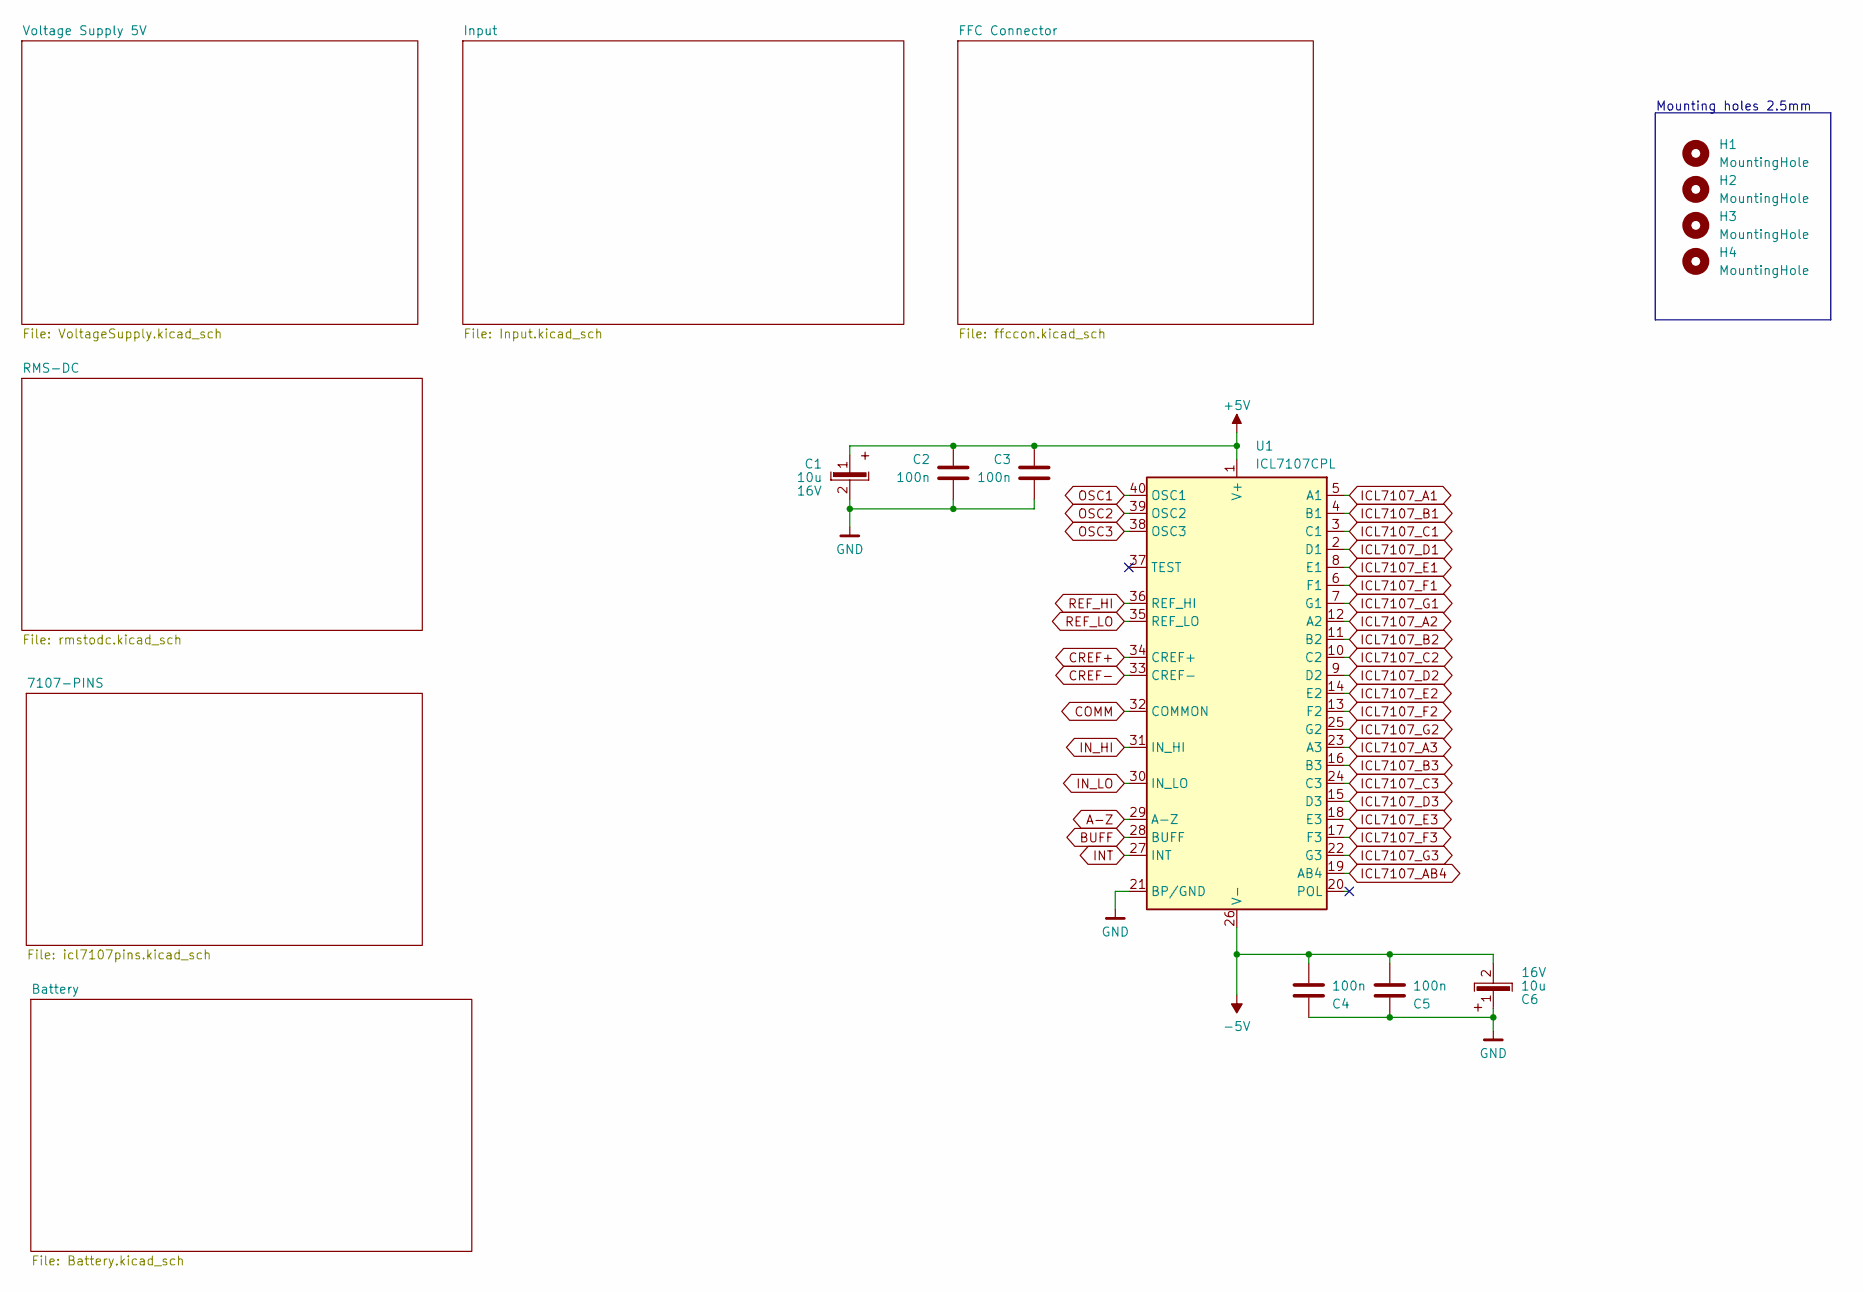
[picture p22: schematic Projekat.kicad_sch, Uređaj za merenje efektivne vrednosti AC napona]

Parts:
C1, C6: 10u; C_0805_2012Metric; Rated Voltage 16V
C2, C3, C4, C5: 100n; C_0603_1608Metric
H1, H2, H3, H4: MountingHole; MountingHole_2.5mm
U1: ICL7107CPL; DIP-40_W15.24mm

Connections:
+5V: C1.1, C2.1, C3.1, U1.1 (V+); also elsewhere on the board
-5V: C4.2, C5.2, C6.2, U1.26 (V-); also elsewhere on the board
A-Z: U1.29 (A-Z); also elsewhere on the board
AD737_COM: U1.30 (IN_LO), U1.32 (COMMON), U1.35 (REF_LO); also elsewhere on the board
BUFF: U1.28 (BUFF); also elsewhere on the board
CREF+: U1.34 (CREF+); also elsewhere on the board
CREF-: U1.33 (CREF-); also elsewhere on the board
ICL7107_A1: U1.5 (A1); also elsewhere on the board
ICL7107_A2: U1.12 (A2); also elsewhere on the board
ICL7107_A3: U1.23 (A3); also elsewhere on the board
ICL7107_AB4: U1.19 (AB4)
ICL7107_B1: U1.4 (B1); also elsewhere on the board
ICL7107_B2: U1.11 (B2); also elsewhere on the board
ICL7107_B3: U1.16 (B3); also elsewhere on the board
ICL7107_C1: U1.3 (C1); also elsewhere on the board
ICL7107_C2: U1.10 (C2); also elsewhere on the board
ICL7107_C3: U1.24 (C3); also elsewhere on the board
ICL7107_D1: U1.2 (D1); also elsewhere on the board
ICL7107_D2: U1.9 (D2); also elsewhere on the board
ICL7107_D3: U1.15 (D3); also elsewhere on the board
ICL7107_E1: U1.8 (E1); also elsewhere on the board
ICL7107_E2: U1.14 (E2); also elsewhere on the board
ICL7107_E3: U1.18 (E3); also elsewhere on the board
ICL7107_F1: U1.6 (F1); also elsewhere on the board
ICL7107_F2: U1.13 (F2); also elsewhere on the board
ICL7107_F3: U1.17 (F3); also elsewhere on the board
ICL7107_G1: U1.7 (G1); also elsewhere on the board
ICL7107_G2: U1.25 (G2); also elsewhere on the board
ICL7107_G3: U1.22 (G3); also elsewhere on the board
INT: U1.27 (INT); also elsewhere on the board
IN_HI: U1.31 (IN_HI); also elsewhere on the board
OSC1: U1.40 (OSC1); also elsewhere on the board
OSC2: U1.39 (OSC2); also elsewhere on the board
OSC3: U1.38 (OSC3); also elsewhere on the board
REF_HI: U1.36 (REF_HI); also elsewhere on the board

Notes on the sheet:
Mounting holes 2.5mm

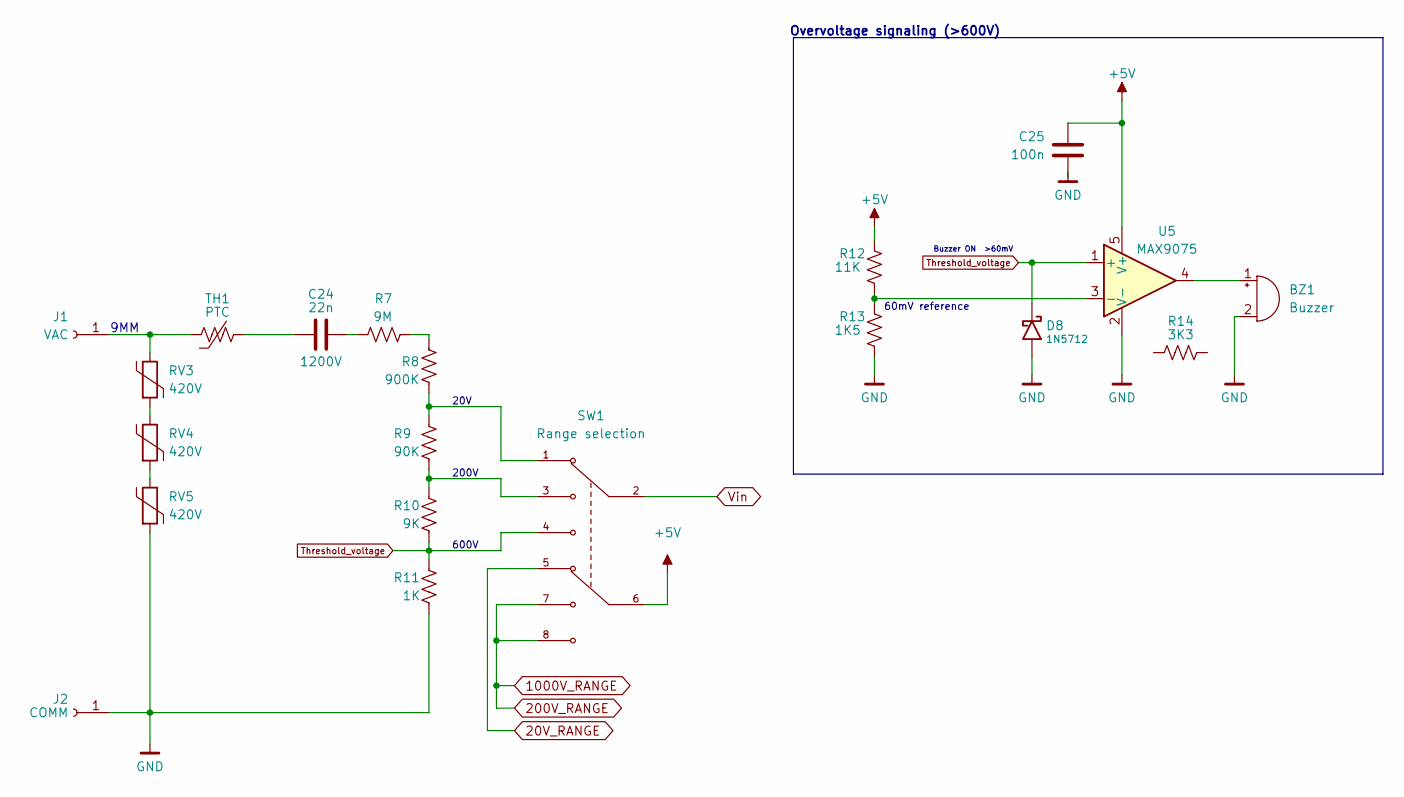
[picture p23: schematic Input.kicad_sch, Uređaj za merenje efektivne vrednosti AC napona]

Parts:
BZ1: Buzzer; Buzzer_12x9.5RM7.6
C24: 22n; C_1812_4532Metric; Rated Voltage 1200V
C25: 100n; C_0603_1608Metric
D8: 1N5712; D_DO-35_SOD27_P7.62mm_Horizontal
J1: VAC; CONN1_FCR7350R_CLF
J2: COMM; CONN1_FCR7350R_CLF
R7: 9M; R_1210_3225Metric
R8: 900K; R_1210_3225Metric
R9: 90K; R_1206_3216Metric
R10: 9K; R_1206_3216Metric
R11: 1K; R_1206_3216Metric
R12: 11K; R_1206_3216Metric
R13: 1K5; R_1206_3216Metric
R14: 3K3; R_1206_3216Metric
RV3, RV4, RV5: 420V; RV_Disc_D9mm_W3.3mm_P5mm
SW1: Range selection; SW_EG2310
TH1: PTC; R_Axial_DIN0414_L11.9mm_D4.5mm_P7.62mm_Vertical
U5: MAX9075; SOT-23-5

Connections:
20V_RANGE: SW1.5; also elsewhere on the board
1000V_RANGE: SW1.7, SW1.8; also elsewhere on the board
+5V: C25.1, R12.1, SW1.6, U5.5 (V+); also elsewhere on the board
unnamed: BZ1.1 (-), U5.4
unnamed 39: C24.1, TH1.2; also elsewhere on the board
unnamed: C24.2, R7.1
unnamed: R7.2, R8.2
unnamed: R8.1, R9.1, SW1.1
unnamed: R9.2, R10.1, SW1.3
unnamed: RV3.2, RV4.1
unnamed: RV4.2, RV5.1
unnamed: R12.2, R13.1, U5.3 (-)
Threshold_voltage: D8.1 (K), R10.2, R11.1, SW1.4, U5.1 (+)
Vin: SW1.2; also elsewhere on the board

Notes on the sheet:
600V
20V
Buzzer ON >60mV
9MM
60mV reference
200V
Overvoltage signaling (>600V)

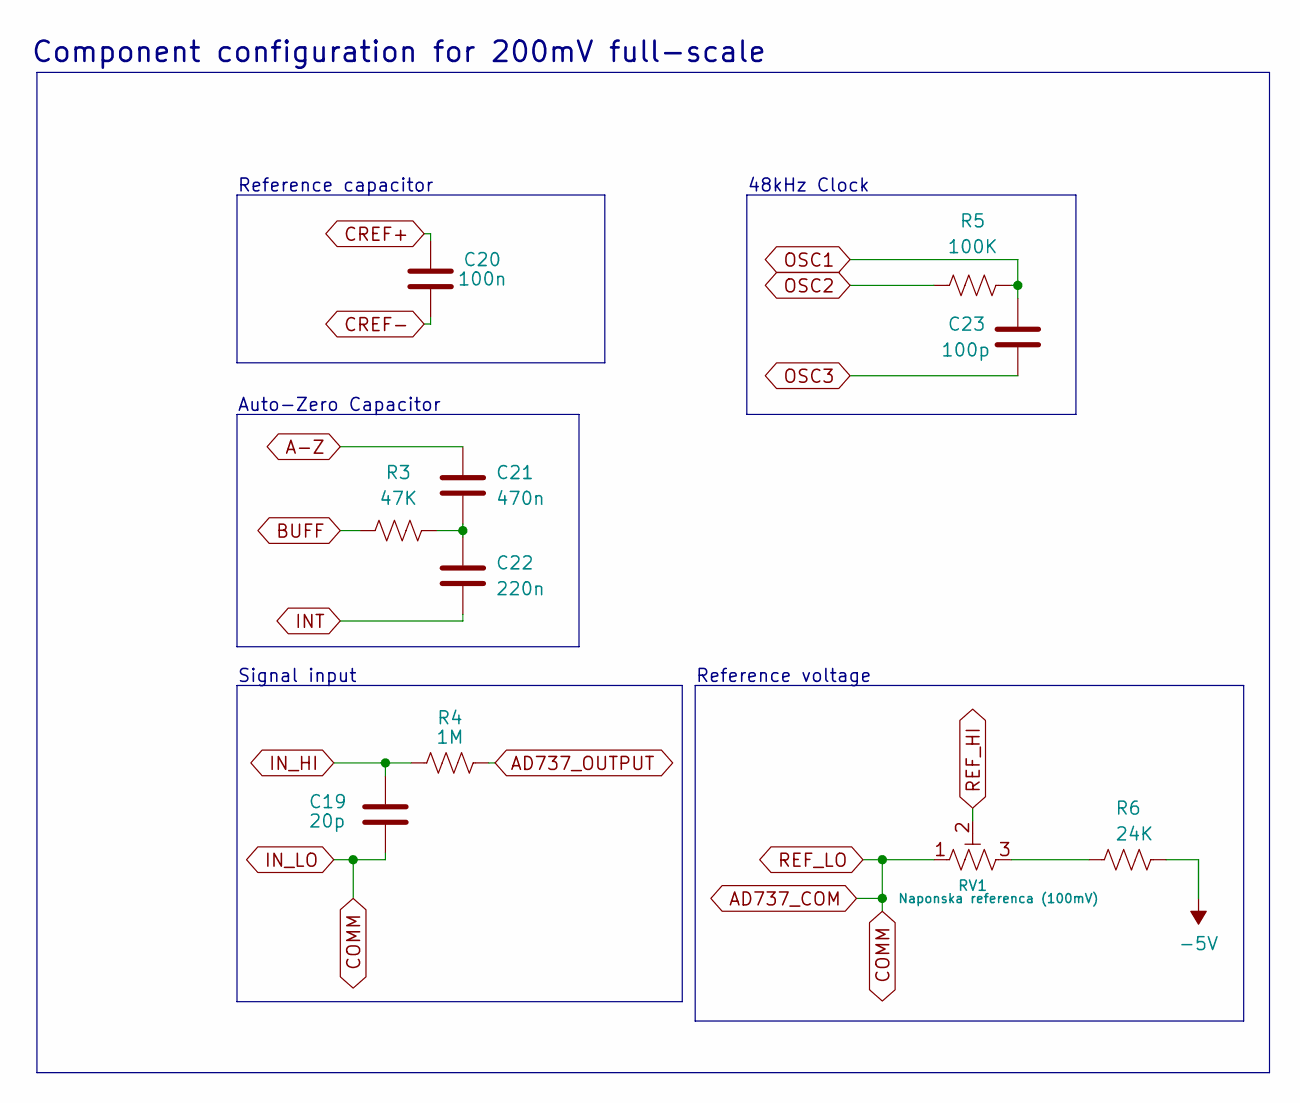
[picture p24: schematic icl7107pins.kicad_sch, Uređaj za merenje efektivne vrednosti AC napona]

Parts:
C19: 20p; C_0603_1608Metric
C20: 100n; C_0603_1608Metric
C21: 470n; C_0603_1608Metric
C22: 220n; C_0603_1608Metric
C23: 100p; C_0603_1608Metric
R3: 47K; R_1206_3216Metric
R4: 1M; R_Axial_DIN0204_L3.6mm_D1.6mm_P5.08mm_Horizontal
R5: 100K; R_1206_3216Metric
R6: 24K; R_1206_3216Metric
RV1: Naponska referenca (100mV); Potentiometer_Bourns_3266W_Vertical

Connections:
-5V: R6.1; also elsewhere on the board
A-Z: C21.2; also elsewhere on the board
AD737_COM: C19.2, RV1.1; also elsewhere on the board
AD737_OUTPUT: R4.2; also elsewhere on the board
BUFF: R3.1; also elsewhere on the board
CREF+: C20.1; also elsewhere on the board
CREF-: C20.2; also elsewhere on the board
INT: C22.1; also elsewhere on the board
IN_HI: C19.1, R4.1; also elsewhere on the board
unnamed: C21.1, C22.2, R3.2
unnamed: R6.2, RV1.3
OSC1: C23.1, R5.2; also elsewhere on the board
OSC2: R5.1; also elsewhere on the board
OSC3: C23.2; also elsewhere on the board
REF_HI: RV1.2; also elsewhere on the board

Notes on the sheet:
Auto-Zero Capacitor
Reference capacitor
Reference voltage
Signal input
Component configuration for 200mV full-scale
48kHz Clock

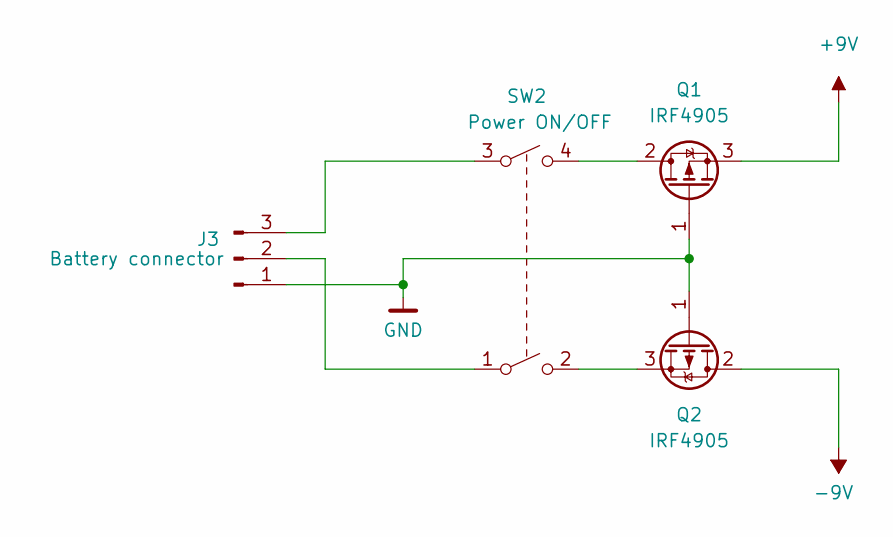
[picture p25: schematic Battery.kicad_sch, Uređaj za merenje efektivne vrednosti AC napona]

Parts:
J3: Battery connector; JST_XH_B3B-XH-A_1x03_P2.50mm_Vertical
Q1, Q2: IRF4905; TO-220-3_Vertical
SW2: Power ON/OFF; SW_CuK_JS202011AQN_DPDT_Angled

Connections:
+9V: Q1.3 (S); also elsewhere on the board
-9V: Q2.2 (D); also elsewhere on the board
unnamed: J3.3 (Pin_1), SW2.3
unnamed: J3.2, SW2.1
unnamed: Q1.2 (D), SW2.4
unnamed: Q2.3 (S), SW2.2

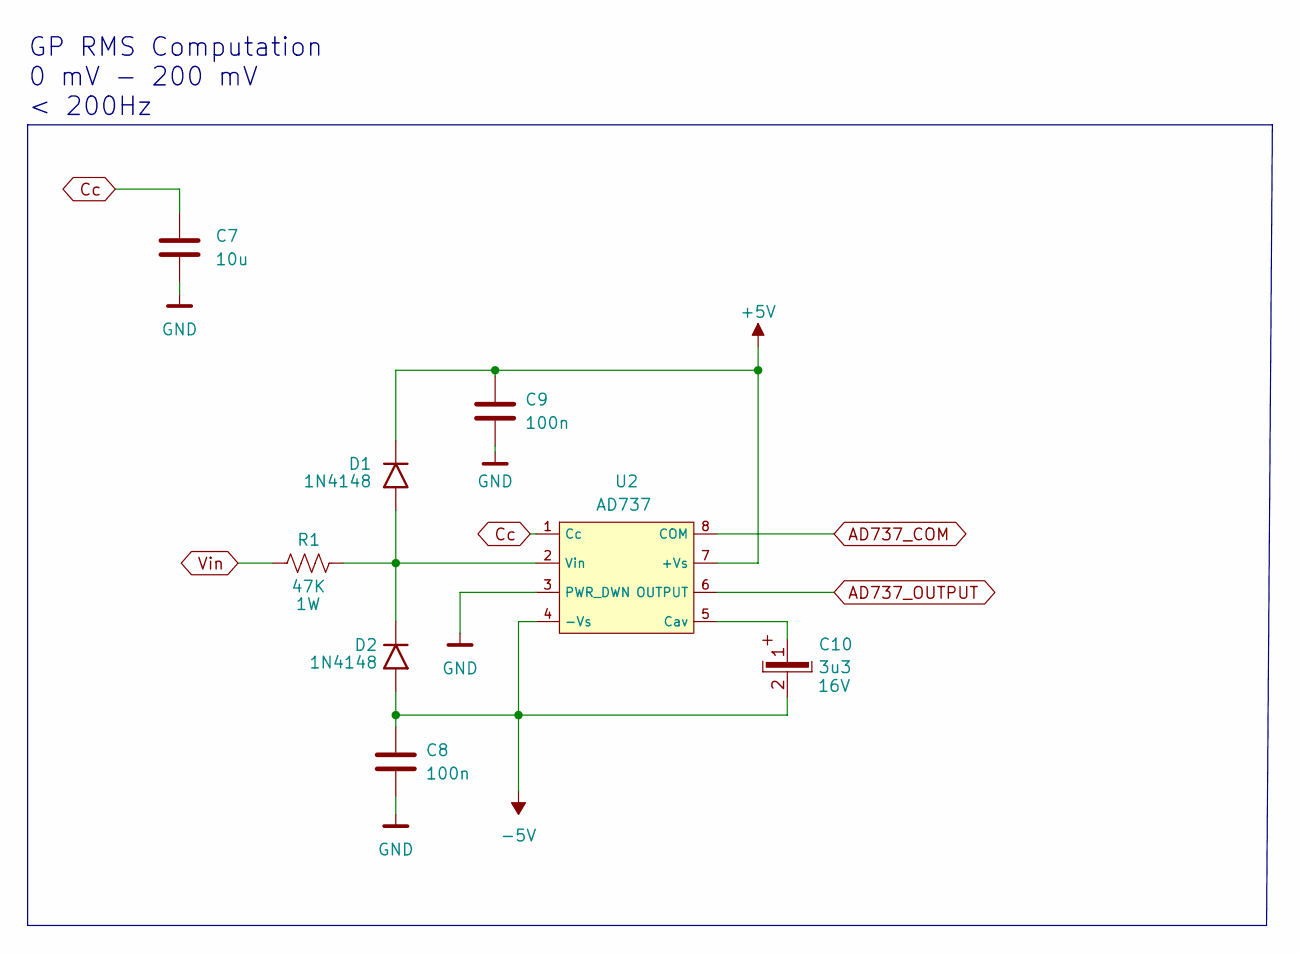
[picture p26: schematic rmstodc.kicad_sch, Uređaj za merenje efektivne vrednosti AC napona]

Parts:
C7: 10u; C_0805_2012Metric
C8, C9: 100n; C_0603_1608Metric
C10: 3u3; C_0805_2012Metric; Rated Voltage 16V
D1, D2: 1N4148; D_DO-35_SOD27_P7.62mm_Horizontal
R1: 47K; R_1206_3216Metric; Power Rating 1W
U2: AD737; DIP-8_W10.16mm

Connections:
+5V: C9.1, D1.1 (K), U2.7 (+Vs); also elsewhere on the board
-5V: C8.1, C10.2, D2.2 (A), U2.4 (-Vs); also elsewhere on the board
AD737_COM: U2.8 (COM); also elsewhere on the board
AD737_OUTPUT: U2.6 (OUTPUT); also elsewhere on the board
Cc: C7.1, U2.1 (Cc)
unnamed: D1.2 (A), D2.1 (K), R1.1, U2.2 (Vin)
unnamed: C10.1, U2.5 (Cav)
Vin: R1.2; also elsewhere on the board

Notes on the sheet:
GP RMS Computation 0 mV - 200 mV < 200Hz

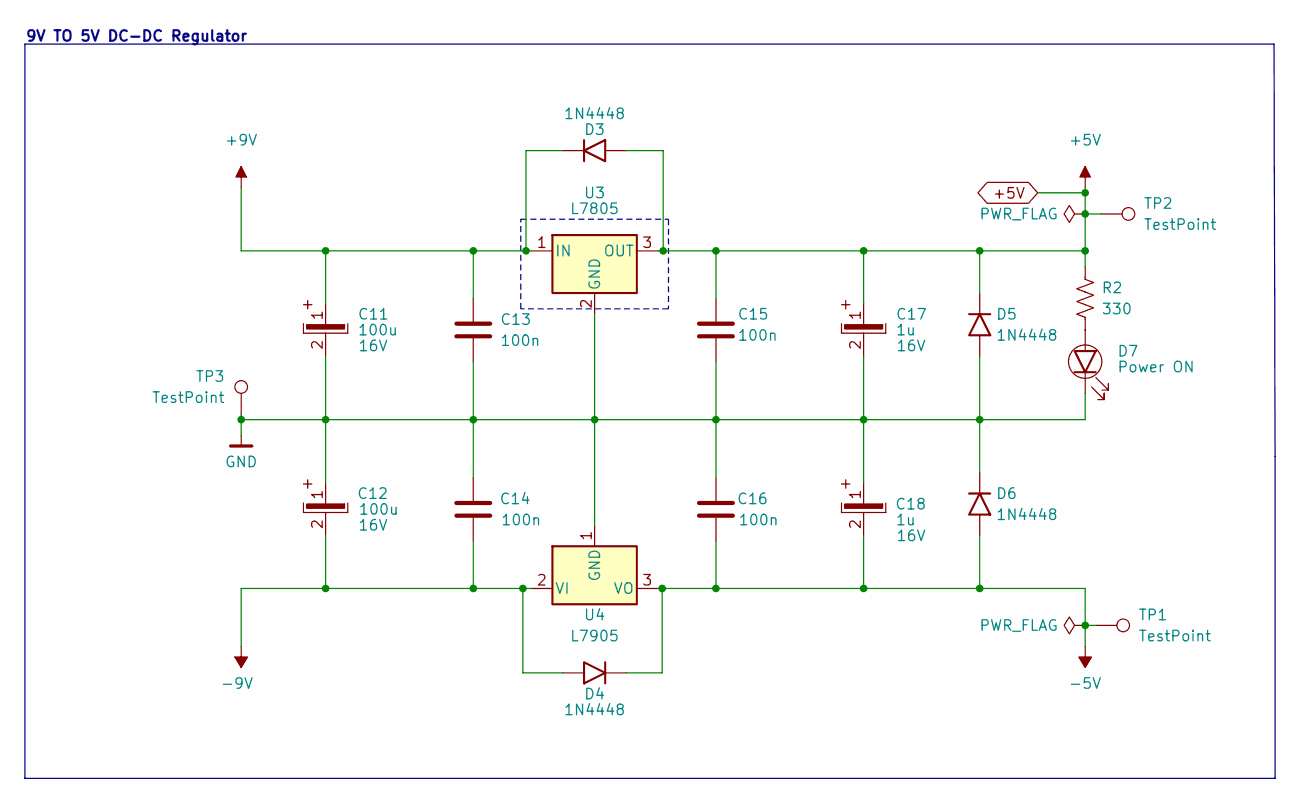
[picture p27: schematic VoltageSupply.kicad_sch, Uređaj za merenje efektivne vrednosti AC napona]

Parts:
C11, C12: 100u; C_0603_1608Metric; Rated Voltage 16V
C13, C14, C15, C16: 100n; C_0603_1608Metric
C17, C18: 1u; C_0805_2012Metric; Rated Voltage 16V
D3, D4, D5, D6: 1N4448; D_DO-35_SOD27_P7.62mm_Horizontal
D7: Power ON; LED_D5.0mm_Horizontal_O6.35mm_Z15.0mm
R2: 330; R_1206_3216Metric
TP1, TP2, TP3: TestPoint; TestPoint_Loop_D2.60mm_Drill0.9mm_Beaded
U3: L7805; TO-220-3_Vertical
U4: L7905; TO-220-3_Vertical

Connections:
+5V: C15.1, C17.1, D3.2 (A), D5.1 (K), R2.1, TP2.1, U3.3 (OUT); also elsewhere on the board
+9V: C11.1, C13.1, D3.1 (K), U3.1 (IN); also elsewhere on the board
-5V: C16.1, C18.2, D4.1 (K), D6.2 (A), TP1.1, U4.3 (VO); also elsewhere on the board
-9V: C12.2, C14.1, D4.2 (A), U4.2 (VI); also elsewhere on the board
unnamed: D7.2 (A), R2.2

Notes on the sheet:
9V TO 5V DC-DC Regulator

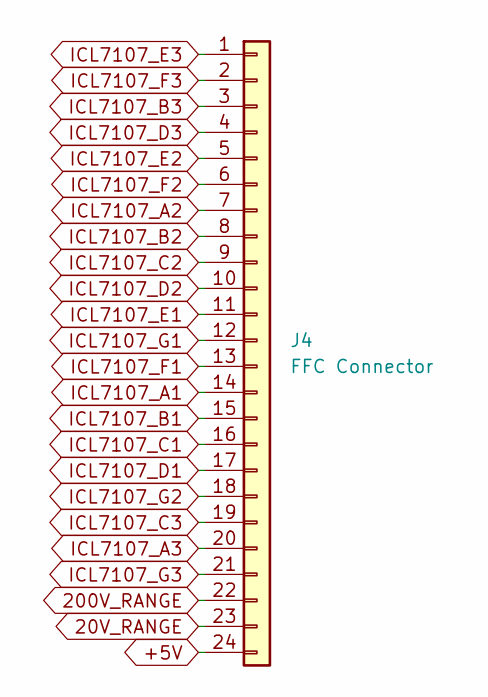
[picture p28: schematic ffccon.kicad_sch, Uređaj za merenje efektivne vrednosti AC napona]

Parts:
J4: FFC Connector; FPC_24

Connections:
20V_RANGE: J4.23; also elsewhere on the board
1000V_RANGE: J4.22; also elsewhere on the board
ICL7107_A1: J4.14; also elsewhere on the board
ICL7107_A2: J4.7; also elsewhere on the board
ICL7107_A3: J4.20; also elsewhere on the board
ICL7107_B1: J4.15; also elsewhere on the board
ICL7107_B2: J4.8; also elsewhere on the board
ICL7107_B3: J4.3; also elsewhere on the board
ICL7107_C1: J4.16; also elsewhere on the board
ICL7107_C2: J4.9; also elsewhere on the board
ICL7107_C3: J4.19; also elsewhere on the board
ICL7107_D1: J4.17; also elsewhere on the board
ICL7107_D2: J4.10; also elsewhere on the board
ICL7107_D3: J4.4; also elsewhere on the board
ICL7107_E1: J4.11; also elsewhere on the board
ICL7107_E2: J4.5; also elsewhere on the board
ICL7107_E3: J4.1; also elsewhere on the board
ICL7107_F1: J4.13; also elsewhere on the board
ICL7107_F2: J4.6; also elsewhere on the board
ICL7107_F3: J4.2; also elsewhere on the board
ICL7107_G1: J4.12; also elsewhere on the board
ICL7107_G2: J4.18; also elsewhere on the board
ICL7107_G3: J4.21; also elsewhere on the board

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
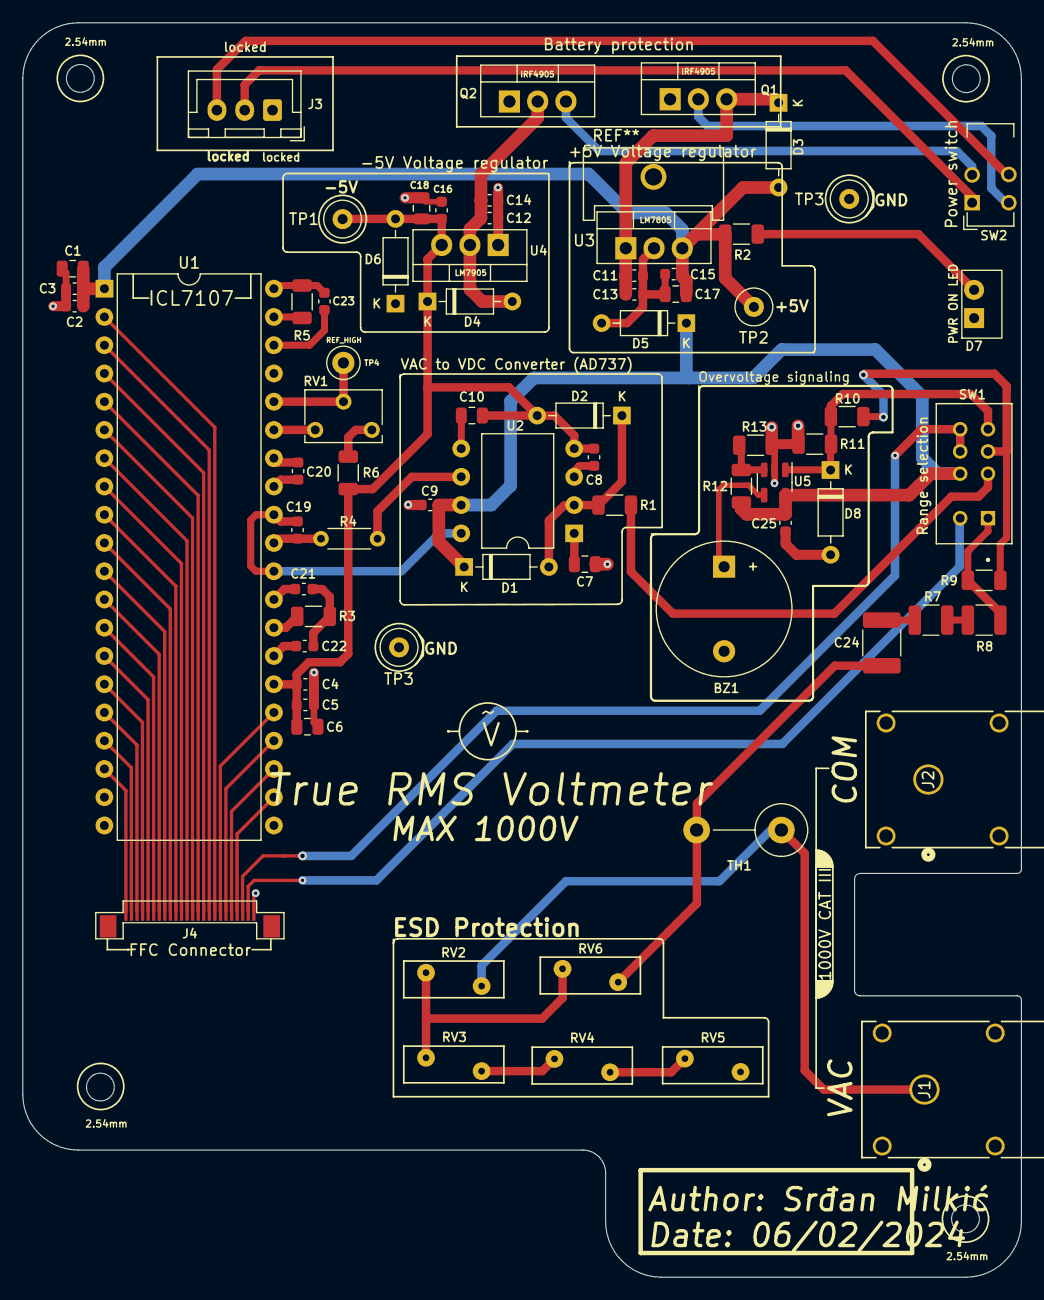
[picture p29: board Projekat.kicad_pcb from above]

Board: 2 copper layers, 89.8 x 112.8 mm, 76 parts (0 on the bottom side), 63 nets.

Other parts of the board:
RV2, RV6: 910V; RV_Disc_D9mm_W3.3mm_P5mm
TP3#2: TestPoint; TestPoint_Loop_D2.60mm_Drill0.9mm_Beaded
TP4: TestPoint_Loop_D2.50mm_Drill1.0mm_LowProfile

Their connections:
unnamed 39: RV6.1; also elsewhere on the board
REF_HI: TP4.1; also elsewhere on the board

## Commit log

2024-03-11 KiCad files, KiCad version 7.0
    [350180-9.step, 532702B02500G--3DModel-STEP-56544.STEP, 532702B02500G.step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]
2024-03-11 Fixing double upload
    [350180-9.step, 532702B02500G--3DModel-STEP-56544.STEP, 532702B02500G.step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]
2024-03-11 Images
    Images for PCB and SCH
2024-03-11 Rename Full schematic.png to FullSchematic.png
2024-03-11 Rename PCB no components.png to PCBnocomponents.png
2024-03-11 Rename PCB with components.png to PCBwithcomponents.png
2024-03-11 !Add Full schematic PDF
    For better quality
2024-05-08 Removed unused files
    [fs.kicad_sch]

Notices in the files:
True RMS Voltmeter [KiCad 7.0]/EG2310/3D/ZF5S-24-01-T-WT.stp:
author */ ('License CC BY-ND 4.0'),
